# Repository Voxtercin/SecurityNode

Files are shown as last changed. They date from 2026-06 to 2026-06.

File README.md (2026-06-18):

# SecurityNode

SecurityNode is an embedded security system based on an **ESP32-C3** microcontroller and an **ESP32-CAM** vision module. The platform monitors physical access events using external sensors and augments a conventional alarm with event-triggered visual verification.

## Overview

The system is designed around a compact PCB and integrates:

- **ESP32-C3** as the central security controller
- **ESP32-CAM** as an auxiliary vision-processing module
- **Door contact** and **PIR motion sensor** for event detection
- **Alarm LED** and **buzzer** (MOSFET-driven) for local indication
- **USB power input** with **3.3 V regulation**

In the planned operating flow (design-stage; firmware not yet written), when a door-opening or motion event is detected, the ESP32-C3 requests the ESP32-CAM to capture and analyze an image. The vision module is intended to determine whether the person entering has a visible or covered face (e.g., helmet, mask, or balaclava). If a suspicious condition is detected, the ESP32-C3 activates the buzzer and alarm LED.

## Repository Structure

> **Project stage:** this is a **design-stage** project (PCB drawn in Altium but not yet
> fabricated; no firmware written). The documentation and design assets are the current
> deliverable. The code/source directories below — `hardware/altium/`, `firmware/esp32c3/`,
> `firmware/esp32cam/`, `software/host/`, `tests/`, and `tools/` — are currently **skeleton
> placeholders (each holds only a `.gitkeep`)**; the substance lives in `docs/` and `assets/`.

```
SecurityNode/
├── assets/              # PCB renders, schematic blocks, and source PDFs
├── docs/
│   ├── hardware/        # Hardware interface and design documentation
│   ├── firmware/        # Firmware architecture and protocols (proposed design)
│   ├── presentation/    # Final presentation (HTML + PDF)
│   ├── software/        # Host-side tools and utilities (proposed design)
│   ├── system/          # System architecture and requirements
│   └── teacher_notes/   # Presentation guidelines
├── hardware/
│   └── altium/          # Altium Designer project files (skeleton — not yet committed)
├── firmware/
│   ├── esp32c3/         # Main controller firmware (skeleton — not yet written)
│   └── esp32cam/        # Vision module firmware (skeleton — not yet written)
├── software/
│   └── host/            # PC-side configuration and monitoring tools (skeleton)
├── tests/               # Validation procedures and bring-up checklists (skeleton)
└── tools/               # Helper scripts, export helpers, and generators (skeleton)
```

## Modular Architecture

- The ESP32-C3 acts as the **central security controller**, managing sensor inputs and actuators.
- The ESP32-CAM functions as an **auxiliary vision-processing module**.
- The system remains operational as a **basic alarm** even if the vision module is not used.
- Provides an **intelligent upgrade path** for advanced threat detection.

## Academic Context

This project integrates:

- Power regulation
- Digital input conditioning
- Embedded control
- Actuator driving
- Sensor-based event detection
- Computer vision assistance

into a compact PCB-based security platform. It is developed as a **Final Project of Electronic Design**.

## License

This project is licensed under the [MIT License](LICENSE).

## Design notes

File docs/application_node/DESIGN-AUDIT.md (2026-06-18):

# SecurityNode — Design Documentation Audit

> Audit of the SecurityNode docs against the authoritative hardware ground truth
> (schematic netlist `SecurityNode.pdf`, rendered schematic, and Altium LiveBOM
> `SecurityNode.BomDoc`). Design-stage project: PCB drawn in Altium but not built,
> no firmware written. This report separates what is **true** from what is **false**
> so the application note can be fixed against reality.

---

## 1. Verdict & headline

The **high-level architecture is sound and correctly documented** — two MCUs (ESP32-C3 controller + ESP32-CAM vision slave), door/PIR sensing, LED+buzzer alarm, USB power with 3.3 V regulation, and a CAM-absent fallback are all accurate. **The hardware-fact layer is broken**: a single wrong ESP32-C3 pin map and a wrong understanding of two key chips (U4 and U5) were authored speculatively and then propagated into nearly every hardware/firmware doc, the bring-up checklist, the application note, *and* `CLAUDE.md` itself. Firmware written against the current pin tables would not work on the real board, so these are contradictions/fabrications to fix — not acceptable design latitude.

The root causes are few but pervasive: (a) the CAM UART is on the wrong GPIOs, (b) the buzzer is on the wrong GPIO, (c) UART0/programming is mis-described as a "USB-UART through U5" path when the C3 actually uses **native USB**, (d) U5 is called a programming multiplexer when it is an automatic presence-gated isolation switch, (e) U4 is called a whole-board current limiter when it only gates the CAM, and (f) the LDO and a few diode/LED/resistor designators are swapped. Fix those six root facts once and most of the documentation set becomes correct.

---

## 2. Verified correct (keep trusting these)

These claims were checked and **match the schematic/BOM**. They are safe to keep and to build on:

**Concept & system level**
- Two-MCU architecture: **U3 = ESP32-C3-WROOM-02-N4** (controller/master) + **ESP32-CAM** vision module that mounts on header **J3** (UART1 slave). (README, system_overview, firmware_architecture)
- Event flow concept: door/motion → C3 asks CAM to capture+judge face coverage → buzzer+LED if suspicious → degrade to basic alarm if CAM absent/times out. (Correct as a *proposal* — see §5.)
- Power input is **J2 USB Mini-B** (KH-MINI-SMT-5P-Cu), VBUS 5 V, with a 3.3 V regulated rail. (README, system_overview, power_architecture)

**Correct pins (the few that are right)**
- **Door contact = GPIO4** (IO4 / DOOR_GPIO4, from J4). ✔
- **PIR motion = GPIO5** (IO5 / PIR_GPIO5, from J5). ✔
- **Alarm LED = GPIO6** (IO6 / LED_ALERT). ✔ *(pin is right; the LED's designator/resistor are wrong — see §4)*
- Both sensor inputs are inputs; door has real hardware debounce on board. ✔

**Correct parts / topology**
- **Q1 = DN2302S** N-MOSFET, low-side buzzer switch; gate from the buzzer GPIO via **R12 100R**, with **R14 10k** pulldown. ✔ (pin number is wrong, see §3)
- **LS1 = KPEG242-5V** buzzer, on the **5 V rail**, low-side switched by Q1. ✔
- **D5 = XL-2012SURC** red 0805 LED is the actual alarm-LED part. ✔
- **U2 = USBLC6-2P6** ESD array on USB D+/D−; series **R3/R4 22R** to the C3. ✔
- **U4 = TPS2553DBVR** adjustable-ILIM USB power switch (ILIM via R13 21k5); EN via R9 100R. ✔ *(part right; role overstated — see §3)*
- **U1 = AP2112K-3.3** LDO ratings (≤6 V in, 3.3 V/600 mA out, thermal+current limit). ✔ *(ratings right; designator wrong — see §4)*
- **FB1 = HCB1608KF-600T20** ferrite (60 Ω@100 MHz, 2 A, 0603) in the VBUS→5 V path. ✔
- **SW1 = BOOT** (GPIO9, R1 pull-up), **SW2 = EN/reset** (R2 pull-up); manual bootloader = hold SW1, tap SW2. ✔
- The C3↔CAM UART1 link physically runs through **J3** and through **U5**, and both directions pass U5. ✔ (the *pins* and U5's *role description* are wrong elsewhere)
- README contains **no** pin/designator errors (it has no pin numbers) — fully accurate at its level of detail.

---

## 3. Critical errors (must fix) — HIGH severity

These are hardware-fact contradictions or fabrications. Firmware or bring-up done against them will fail. **Recurring** errors are grouped; the same wrong fact appears across many files.

| Location (recurring across docs) | What the docs say | The truth (ground truth) |
|---|---|---|
| **CAM UART1 pins** — mcu_interfaces (GPIO8/9), esp32cam_interface, firmware_architecture, cam_protocol, application_node (A2, pinout, block diag), **CLAUDE.md** | C3↔CAM UART1 is on **GPIO8 / GPIO9** | UART1 is **IO0 = RX (pin18)** and **IO1 = TX (pin17)**, via R20/R21 1k and U5. GPIO8 = STRAP_GPIO8, GPIO9 = BOOT_GPIO9 (SW1 BOOT). Note **IO0=RX, IO1=TX**. |
| **Buzzer pin** — mcu_interfaces, alarm_subsystem, firmware_architecture, application_node (pinout + block diag), **CLAUDE.md** | Buzzer / Q1 gate is on **GPIO7** | Buzzer is **IO10 (BUZZER)** → R12 100R → Q1 gate. **IO7 = CAM_EN** (drives U4 TPS2553 enable via R9), not the buzzer. |
| **Programming / UART0** — mcu_interfaces, firmware_architecture, application_node, **CLAUDE.md** | UART0 debug/programming is **GPIO1/2**, "routed through U5", USB-UART for flashing | UART0 is **RXD=GPIO20 (pin11)** / **TXD=GPIO21 (pin12)**, wired **direct to J1**, **never through U5**. GPIO1=UART1_TX, GPIO2=STRAP_GPIO2. |
| **C3 programmed via "USB-UART bridge"** — mcu_interfaces, firmware_architecture (Arduino step), esp32cam_interface, host_tools, bringup (CP210x), application_node (A6) | C3 is flashed over a USB→UART bridge / CP210x through J2; U5 muxes that UART | **No bridge chip exists.** The C3 is programmed over its **NATIVE USB** (USB-Serial/JTAG): J2 → U2 USBLC6 → R3/R4 22R → IO18(D−)/IO19(D+). PC enumerates the C3's built-in USB CDC, never a CP210x. |
| **BOOT/EN on GPIO0/GPIO3** — mcu_interfaces pinout | GPIO0 = BOOT (SW1); GPIO3 = EN (SW2) | **BOOT is IO9** (BOOT_GPIO9, R1, SW1). **EN is the dedicated EN pin (pin2)**, not a GPIO (ESP_EN, R2, C9, SW2). IO0 = UART1_RX; IO3 = CAM_FAULT. |
| **U4 (TPS2553) role** — system_overview, mcu_interfaces (buzzer "via TPS2553"), power_architecture, alarm_subsystem, application_node, bringup framing | U4 is a whole-board / USB current limiter / "power distribution"; the 5 V rail and buzzer flow through it | U4 is a **dedicated power GATE for the ESP32-CAM only**: IN=5 V rail, OUT=**CAM_5V** (J3 P$9 / J7 pin6). EN via IO7/CAM_EN; ILIM R13 21k5; FAULT→IO3; **R11 100k pulldown holds it OFF by default**. It does **not** feed the 5 V rail, LDO, or buzzer, and does **not** protect the USB host — **F1 PTC fuse** does. |
| **U5 (SN74LVC2G66) role** — system_overview, mcu_interfaces, esp32cam_interface (whole "USB-UART mux" section), host_tools, bringup, application_node | U5 is a USB-to-UART **programming multiplexer** that switches the USB UART between C3 and CAM (CTRL LOW/HIGH, host-selectable) | U5 is a **series isolation/disconnect switch on the C3↔CAM UART1 link only**. Control pins 1C/2C are **hard-tied to CAM_3V3** (the CAM's own 3.3 V output) → **automatic presence-gating**: closes only when a powered CAM is seated, opens when absent. **Not** a USB mux, **not** on UART0/USB, **not** host-controllable. |
| **Omitted PTC fuse F1** — power_architecture power tree | Input chain is TVS → ferrite → USBLC6 (no fuse) | First element after VBUS is **F1 PTC fuse** (Littelfuse 1206L075/16V, 750 mA hold / 1.5 A trip), in series before the D1 clamp and FB1. Whole-board USB over-current = F1, **not** U4. |
| **5 V rail topology** — power_architecture (TPS2553 in series ahead of rail; CAM 5V + buzzer on one node) | TPS2553 feeds the whole 5 V rail and the LDO; CAM 5 V and buzzer share that node | VBUS → F1 → D1+C1 → FB1 → **5 V RAIL**, which feeds **U1 LDO and U4 in parallel** (plus LS1, J5 PIR VCC). **CAM_5V is the gated U4 output (separate node)**; buzzer/PIR are on the ungated 5 V rail. |
| **CAM IO0 driven by C3 GPIO10** — mcu_interfaces (GPIO10=CAM_BOOT), esp32cam_interface | C3 GPIO10 drives CAM IO0 boot strap | **No C3 GPIO drives CAM IO0.** CAM GPIO0 (B_GPIO0_CAM, J3 P$6) is asserted only by the **J6 2-pin jumper** (+ J7 pin4, R17 10k). **IO10 = BUZZER.** |
| **Fabricated aux GPIOs / headers** — mcu_interfaces (GPIO11/12 AUX on J6/J7), sensor_interfaces (J6/J7 expansion, GPIO11/12 spare) | J6/J7 are general-purpose expansion headers exposing spare GPIO11/GPIO12 + 3.3V/5V | **Fabricated.** GPIO11/12 are not broken out (GPIO11 is internal/flash on WROOM). **J6 = 2-pin CAM-GPIO0 download jumper.** **J7 = 6-pin ESP32-CAM programming header** (1=GND, 2=CAM_TXD_RAW, 3=CAM_RXD_RAW, 4=B_GPIO0_CAM, 5=CAM_3V3, 6=CAM_5V). |
| **CAM debug "through the board's USB"** — mcu_interfaces, esp32cam_interface, bringup (USB→CAM switchover) | The CAM is programmed/debugged through the board's USB by switching U5 | The CAM is programmed **out-of-band via J7** with an **external USB-UART adapter** + J6 jumper. No on-board USB path reaches the CAM. |
| **PIR VCC selectable 3.3 V/5 V** — sensor_interfaces | PIR VCC (J5 pin1) can be 3.3 V or 5 V | J5 pin1 (PIR VCC) is **hard-wired to the 5 V rail only**. The board cannot supply 3.3 V to the PIR connector. |
| **J3 pin map** — esp32cam_interface | Generic AI-Thinker order: pin1=3V3, pin3=5V, pin5=TXD, pin6=RXD, pin7=IO0, pins 8-14 = SD/PSRAM GPIOs | Schematic J3: **P$2=CAM_TXD_RAW, P$3=CAM_RXD_RAW, P$6=B_GPIO0_CAM, P$8=CAM_3V3 (CAM's own 3V3, gates U5), P$9=CAM_5V**. SD/PSRAM breakouts are fabricated; CAM_3V3 is **not** fed from the AP2112K. |

**Net pin map to author against (authoritative ESP32-C3 / U3):**

| GPIO | Net / function |
|---|---|
| EN (pin2) | ESP_EN (reset, SW2, R2) |
| IO0 | UART1_RX (CAM link RX, ← R20 1k ← U5) |
| IO1 | UART1_TX (CAM link TX, → R21 1k → U5) |
| IO2 | STRAP_GPIO2 |
| IO3 | CAM_FAULT (← U4 FAULT, R10 10k pull-up) |
| IO4 | DOOR_GPIO4 (door, J4) |
| IO5 | PIR_GPIO5 (PIR, J5) |
| IO6 | LED_ALERT (→ R15 330R → D5) |
| IO7 | CAM_EN (→ R9 100R → U4 EN) |
| IO8 | STRAP_GPIO8 |
| IO9 | BOOT_GPIO9 (BOOT, SW1, R1) |
| IO10 | BUZZER (→ R12 100R → Q1 → LS1) |
| IO18 | USB_D_N (→ R3 22R → U2 → J2) |
| IO19 | USB_D_P (→ R4 22R → U2 → J2) |
| GPIO20 (pin11) | UART0_RX → J1-3 |
| GPIO21 (pin12) | UART0_TX → J1-2 |

---

## 4. Secondary errors — MEDIUM severity

Wrong but lower-blast-radius: mostly designator swaps that mislead bring-up/BOM cross-reference but don't by themselves break firmware logic.

| Location | What the docs say | The truth |
|---|---|---|
| LDO designator — system_overview, esp32cam_interface, power_architecture, bringup, **(appears throughout)** | AP2112K LDO is **U2** | AP2112K-3.3 LDO is **U1**. **U2 = USBLC6** ESD array. (U3=C3, U4=TPS2553, U5=switch.) |
| Alarm LED designator — mcu_interfaces, alarm_subsystem | Alarm LED is **D4**, resistor **R16** | LED is **D5** (XL-2012SURC); series resistor is **R15 330R**. **D4 = BAT54S** PIR clamp; **R16 = 10k** PIR bias. |
| Input TVS designator — power_architecture, bringup | USB input TVS is **D2** | VBUS input TVS (SMF5.0CA) is **D1**. **D2 = PSBD1DF40V1H Schottky 40V 1A** door clamp. |
| J1 pin order — mcu_interfaces | J1: 1=GND, 2=EN, 3=BOOT, 4=RX, 5=TX, 6=GND | J1: 1=GND, **2=UART0_TX (GPIO21), 3=UART0_RX (GPIO20), 4=BOOT_GPIO9, 5=ESP_EN**, 6=GND. |
| Decoupling table — power_architecture | C3=22µF bulk, C4=470nF, specific C5–C16 value map presented as fact | 22µF VBUS bulk is **C1** (not C3; C3 is a 100nF USB-data decoupler); 470nF = C2/C10 (C10=door debounce). The whole designator→value map is inconsistent with the schematic. |
| "5 V unregulated rail" — sensor_interfaces | 5 V pin is an "unregulated rail" | 5 V rail is filtered/protected (F1 PTC + FB1 ferrite + clamps); CAM_5V is additionally **gated/current-limited by U4**. |
| Sensor ESD "not implemented" — sensor_interfaces | No sensor-connector ESD on the PCB | **Partly implemented**: PIR line has **D6** (SMF5.0CA TVS); door has **D2** clamp + RC. |
| GPIO13–21 "unused" — mcu_interfaces | GPIO13–21 free for expansion | GPIO18/19 = native-USB D−/D+; GPIO20/21 = UART0 to J1. In use. |
| Power budget framing — power_architecture, application_node (CAM 200mA@3.3V row) | TPS2553 limit sized as whole-board USB limiter; CAM modeled at 3.3 V 200 mA | U4 gates only the CAM branch (ILIM R13); CAM is fed from **CAM_5V** (gated 5 V), peaks ~500 mA — not 200 mA on 3.3 V. F1 handles whole-board over-current. |
| A4 power rails — application_node | AP2112K 3.3 V rail supplies C3, CAM, sensors, indicators | 3.3 V rail supplies **C3 + U5 only**. CAM runs on **CAM_5V** + its own **CAM_3V3**; PIR + buzzer are on the **5 V rail**. |
| A3 / PIR "3.3 V logic" — application_node | PIR output is a clean 3.3 V logic signal | PIR is **5 V-powered**; signal reaches IO5 through a clamp/divider (R16/R18 100k + BAT54S D4). Qualify accordingly. |
| cam_protocol checksum example — cam_protocol.md line 152 | RESULT example "0xAA 0x02 0x82 0x01 0x80", checksum = 0x80 | `0x02 ^ 0x82 ^ 0x01 = **0x81**`. Frame should be `0xAA 0x02 0x82 0x01 **0x81**`. (Confirmed in file: line 152 prints `= 0x80`.) |

---

## 5. Design proposals (not wrong — but unverifiable, label them "proposed")

These are forward-looking firmware/host/protocol designs. **No firmware or host code exists** (every code dir holds only `.gitkeep`). Nothing in the hardware contradicts them; they are legitimate for a theory-stage note **as long as they are explicitly framed as proposed, not as-built.**

- **CAM UART wire protocol** (cam_protocol.md): frame `0xAA | LENGTH | CMD_ID | PAYLOAD | XOR-checksum`; commands 0x01/0x02/0x03; responses 0x81–0x84; result/status/error code tables; 115200 8N1. Internally consistent **except the one checksum-example arithmetic slip** (§4) and the leftover "let me recalculate" editorial stumble in the CMD_CAPTURE example (~lines 62–82) — clean both up so an implementer doesn't copy a bad literal.
- **FSM**: INIT→ARMED→TRIGGERED→VISION_CHECK→{CLEAR/ALARM}→ARMED, 5 s VISION_CHECK timeout → fallback ALARM, basic-alarm-without-CAM. Consistent across system_overview, firmware_architecture, alarm_subsystem, application_node.
- **Firmware structure / RTOS task layout / build-flash** (PlatformIO primary, ESP-IDF/Arduino alt). Explicitly "Proposed" — fine; only the "USB-UART bridge" wording in the Arduino step is wrong (§3).
- **Host tools** (config util, log viewer, firmware updater, serial monitor, dashboard). Fine — except the two U5 "toggle/select a module" claims, which are hardware-false (§3).
- **Power budget** magnitudes, debounce timings, baud/framing, Wi-Fi/BLE/MQTT/OTA options, vision workflow command names — all acceptable estimates/choices; relabel as proposed and align the CAM rail/load with reality.

---

## 6. Application note (`application_node.tex`) — remediation plan

**Good news first:** the note's **structure is exactly right** for a design deliverable — explicit assumptions table, requirements with traceability matrix, FSM, UART protocol (frame/checksum rule correct), and a theoretical verification plan. The *form* is publishable. The problem is that its **hardware facts were inherited from the wrong source docs** (`mcu_interfaces.md` + the U4/U5 misconceptions), so the technically-checkable content is wrong in the same places as everything else.

**Exact fixes to make in the `.tex`:**

1. **Pinout table (`tab:pinout`, lines ~293–302)** — replace with the authoritative map in §3:
   - BUZZER_DRV: GPIO7 → **GPIO10**.
   - CAM_TX/CAM_RX: GPIO8/GPIO9 → **IO1 (TX) / IO0 (RX)** (and fix the swap: IO0=RX, IO1=TX).
   - USB_TX/USB_RX: GPIO1/GPIO2 "through U5" → **GPIO21/GPIO20, direct to J1, not through U5**.
   - VBUS row: "current-limited by TPS2553" → **"over-current protected by PTC fuse F1; TPS2553 gates CAM_5V only."**
   - Keep DOOR_IN=GPIO4, PIR_IN=GPIO5, ALARM_LED=GPIO6 (correct).
2. **Assumption A2 (line ~158)** — "ESP32-CAM via UART1 (GPIO8/9)" → **"UART1 on IO0=RX / IO1=TX, isolated by U5 (CAM-presence-gated)."** Keep 115200.
3. **Assumption A4 (line ~160) + Power section (lines ~337–339)** — rewrite the rail tree: VBUS→**F1**→D1/C1→**FB1**→5 V rail → (U1 LDO ∥ U4 in parallel). State that the 3.3 V rail feeds **C3 + U5 only**; the CAM is on **CAM_5V (U4-gated)** + its own **CAM_3V3**; PIR + buzzer are on the **5 V rail**. Remove "TPS2553 distributes power [board-wide]."
4. **Assumption A6 (line ~162) + R6** — "USB-UART channel for programming" → **"native USB (USB-Serial/JTAG) on IO18/IO19; separate UART0 debug header J1 on GPIO20/21."** No bridge chip.
5. **U4 / U5 descriptions (power section + PCB checklist line ~396)** — U4 = **CAM-only power gate** (EN via IO7/CAM_EN, ILIM R13 21k5, default-OFF via R11). U5 = **presence-gated series isolation switch on the C3↔CAM UART1 link** (not a programming-path mux). Delete "verify U5 routing for programming-path selection."
6. **Block diagram (`fig:appnode-block`, lines ~258–262)** — buzzer node GPIO7 → **GPIO10**; CAM node GPIO8/9 → **IO0/IO1**; Host node "USB UART0" → **"native USB (IO18/19)"** with UART0/J1 shown as a separate debug header.
7. **Output drive (line ~372)** — "GPIO drives the MOSFET gate directly" → **"via R12 100R series, R14 10k pulldown."**
8. **Power budget (`tab:power`, line ~356)** — move CAM load to **CAM_5V (gated 5 V)** and use the ~500 mA peak the system docs cite, not 200 mA@3.3 V.
9. **Designators** — fix LDO **U1** (not U2), input TVS **D1**, alarm LED **D5**/**R15** anywhere they appear.
10. **Framing** — add an explicit banner: **"Design-stage / not yet fabricated; pin map verified against the schematic netlist."** The note (line ~181) lists `hardware/altium/` as populated source — it currently holds only a `.gitkeep`; relabel artifacts as planned where they don't yet exist.

**Important meta-fix:** `CLAUDE.md` itself encodes the same wrong canonical pin map (GPIO1/2 UART0 "through U5", GPIO7 buzzer, GPIO8/9 CAM UART, U5 "multiplexes the USB UART", TPS2553 as the 5 V switch) and points to `mcu_interfaces.md` as authoritative. **Correct `CLAUDE.md` and `mcu_interfaces.md` first** — they are the upstream that re-seeds every other doc and any future AI edits.

---

## 7. Open questions for the author

1. **Vision approach feasibility (scope this explicitly).** The docs assume the ESP32-CAM can "judge whether a face is covered (mask/helmet/balaclava)" and return a result over UART. If you intend a **pretrained model like YOLO** on the ESP32-CAM, flag the footprint reality: the ESP32 (OV2640 module) is heavily RAM/flash/compute constrained — full YOLO does not fit. Realistic options to evaluate and document as a **decision**: a tiny quantized classifier (e.g. TFLite-Micro / ESP-DL face-or-coverage classifier on small frames), the built-in face-detection primitives, or **offloading inference off-device** (CAM streams a frame; a host/edge does YOLO). The current note treats vision as a black box; pick an approach and write down its memory/latency budget. *(This is the biggest unscoped technical risk in the project.)*

2. **Diode designator split (D1/D3/D6).** BOM has exactly 2× PSBD1DF40V1H (Schottky 40 V 1 A) and 2× SMF5.0CA (TVS 5 V). Only **D2 = Schottky** (schematic prints "40 V 1 A") and **D5 = LED** are certain. The sensible-topology inference is **D1 = VBUS TVS, D3 = 5 V-rail Schottky, D6 = PIR-line TVS**, but per-designator package isn't printed. Confirm from a high-res render or the Altium source before publishing the diode table. **D4 = BAT54S is certain.**

3. **Per-designator R/C → MPN assignment.** The BOM is a value **catalog with no designator column**, so individual R#/C# → exact MPN is inferred from value class + net context. Load-bearing **values** are confirmed (R3/R4=22R, R8/R20/R21=1k, R9/R12=100R, 10k pull-ups, R11/R18/R19=100k, R13=21k5, R15=330R). The exact one-to-one split among same-value parts (e.g. which 100nF is which) is inference — say so, or add a designator column to the BOM.

4. **Sensor conditioning network polarity.** The door (R7 10k / R8 1k / C10 470nF / D2) and PIR (R16/R18 100k, C13/C17, D4, D6) networks' exact pull-up-vs-divider roles and active polarity are inferred from net topology, not annotated. Confirm active-low vs active-high before writing the ISR logic. (The GPIO↔net assignment IO4=door, IO5=PIR is certain.)

5. **BOM hygiene cleanup** (catalogued separately): the SMF5.0CA TVS is mislabeled "TVS 12V" (it's 5 V); the 100nF cap description says "0201" but the footprint is 0603; F1 has a stray "YTL " prefix on the MPN; J2 lists manufacturer EDAC but the MPN is Kinghelm; several parts use non-standard `MF=`/`MP=` keys or corrupted `… Pad Number` keys that drop out of standard exports; the YAGEO 100k links to the wrong (84.5 Ω) datasheet. Worth a pass before any real fabrication/quote.

6. **Connector MPNs.** Only J2 (Mini-USB) and J3 (ESP32-CAM) are catalogued. J1/J4/J5/J6/J7 pin counts/roles are read from schematic symbols, not a catalogued part — assign real connector parts before fabrication.

---

*Audit basis: schematic netlist (authoritative on disagreement), rendered schematic, and Altium LiveBOM. Where three independent passes disagreed, the netlist won.*

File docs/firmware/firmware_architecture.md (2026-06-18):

# Firmware Architecture — SecurityNode

> **Status: PROPOSED / design-stage.** No firmware exists yet (the code directories
> currently hold only `.gitkeep`). Everything in this document — the FSM, the RTOS
> task layout, the proposed `src/` file structure, and the build/flash instructions —
> is a planned design, not as-built. Pin references have been corrected against the
> authoritative schematic netlist (see `docs/application_node/DESIGN-AUDIT.md`).

## Overview

The SecurityNode firmware runs on the **ESP32-C3-WROOM-02-N4** and is responsible for:

1. Sensor input monitoring (door contact, PIR)
2. Alarm output control (buzzer, LED)
3. Communication with the ESP32-CAM vision module
4. System state management and decision logic
5. UART0 debug/console interface (programming itself is over native USB — see *Build and Flash*)

## Main Firmware Loop

```
[Setup]
    |
    +-- Initialize GPIOs
    +-- Initialize UARTs (UART0 debug/console + UART1 CAM link)
    +-- Initialize Wi-Fi (optional, for remote monitoring)
    +-- Set initial state: ARMED
    |
    v
[Main Loop]
    |
    +-- Read sensor inputs (IO4 door, IO5 PIR)
    +-- Evaluate state machine
    +-- Handle UART1 commands from CAM
    +-- Handle UART0 / USB-CDC commands (debug / config)
    +-- Update alarm outputs
    +-- Sleep / yield to RTOS
    |
    v
[Repeat]
```

## State Machine (Proposed)

> Proposed FSM — no firmware implements this yet.

The core of the firmware is a finite-state machine (FSM) that governs system behavior:

```
                    +-----------+
                    |   INIT    |
                    +-----+-----+
                          |
                          v
                    +-----------+
        +---------->|   ARMED   |<----------+
        |           +----+------+           |
        |                |                  |
        |    [No trigger]|   [Sensor event]  |
        |                |                  |
        |                v                  |
        |           +-----------+           |
        |           | TRIGGERED |           |
        |           +----+------+           |
        |                |                  |
        |                v                  |
        |           +-----------+           |
        |           |  VISION   |           |
        |           |  CHECK    |           |
        |           +----+------+           |
        |                |                  |
        |   +------------+------------+      |
        |   |                         |      |
        |   v                         v      |
        | +-----------+           +-----------+ |
        | |  CLEAR    |           |  ALARM    | |
        | |  (safe)   |           |  (active) | |
        | +----+------+           +----+------+ |
        |      |                         |      |
        |      |   [Disarm / timeout]    |      |
        |      |                         |      |
        +------+-------------------------+------+
```

### State Descriptions

| State | Description | Entry Actions | Exit Actions |
|---|---|---|---|
| **INIT** | System startup, self-test | Initialize hardware, test LED/buzzer, check CAM presence | Transition to ARMED |
| **ARMED** | Normal monitoring mode | LED slow blink (1Hz), buzzer OFF, sensors active | — |
| **TRIGGERED** | Sensor event detected | LED fast blink (4Hz), send CMD_CAPTURE to CAM | — |
| **VISION_CHECK** | Waiting for CAM analysis | Maintain fast blink, start 5s timeout timer | — |
| **CLEAR** | CAM reports visible face | Log event, return to ARMED | — |
| **ALARM** | CAM reports suspicious or timeout | LED solid ON, buzzer ON, log event | Wait for disarm or timeout |

## Sensor Input Handling

### Interrupt-Driven vs. Polling

Two approaches are supported:

**Interrupt-Driven (Recommended)**
- Configure IO4 (door, J4) and IO5 (PIR, J5) with `GPIO_INTR_POSEDGE` or `GPIO_INTR_NEGEDGE`.
- ISR sets a flag; main loop processes the flag to avoid long ISRs.
- Low power: ESP32-C3 can enter light sleep and wake on GPIO interrupt.

**Polling**
- Read GPIO states every 50–100ms in the main loop.
- Simpler but higher power consumption and slightly slower response.

### Debounce

- Software timer: ignore state changes within 50ms of the first transition.
- Prevents false triggers from mechanical switch bounce (door contact) or PIR module instability.

> Note: the door has on-board RC hardware debounce, and the PIR is powered from the
> **5V rail** (not 3.3V) with its output conditioned by a clamp/divider network before
> reaching IO5. The active polarity (active-high vs active-low) of both inputs is
> inferred from the conditioning network topology and is **to be confirmed** against the
> schematic before the ISR edge/level logic is finalized.

## UART Communication

### UART0 Debug Header (direct to J1)

| Parameter | Value |
|---|---|
| Port | UART0 (RX = GPIO20 / pin11, TX = GPIO21 / pin12) |
| Routing | Wired **direct to header J1**, NOT through U5 |
| Baud Rate | 115200 |
| Purpose | Debug logs, console, configuration commands; alternate flash header |

> Note: this is a plain UART0 debug/console header. It is **not** the primary
> programming path — the C3 is flashed over its native USB (see *Build and Flash*).

### ESP32-CAM Link UART

| Parameter | Value |
|---|---|
| Port | UART1 (RX = **IO0** / pin18 ← R20 1k ← U5, TX = **IO1** / pin17 → R21 1k → U5) |
| Baud Rate | 115200 |
| Purpose | Capture commands, result codes, status messages |

> Note the direction: **IO0 = UART1_RX, IO1 = UART1_TX**. The link passes through
> **U5 (SN74LVC2G66)**, a CAM-presence-gated series isolation switch whose control pins
> are hard-tied to the CAM's own 3.3V (`CAM_3V3`). U5 auto-connects the link only when a
> powered CAM is seated and auto-disconnects when the CAM is absent/off — firmware does
> **not** control U5, and it is **not** a programming multiplexer.

### UART Command Protocol

See `docs/firmware/cam_protocol.md` for detailed message format.

## Alarm Output Control

### LED (IO6 → R15 330R → D5)

```cpp
// Example (Arduino-style pseudocode)
digitalWrite(ALARM_LED_PIN, HIGH);   // Alarm ON
digitalWrite(ALARM_LED_PIN, LOW);    // Alarm OFF

// Blink pattern
void blinkLED(int freqHz, int durationMs) {
    int periodMs = 1000 / freqHz;
    int cycles = durationMs / periodMs;
    for (int i = 0; i < cycles; i++) {
        digitalWrite(ALARM_LED_PIN, HIGH);
        delay(periodMs / 2);
        digitalWrite(ALARM_LED_PIN, LOW);
        delay(periodMs / 2);
    }
}
```

### Buzzer (IO10 → R12 100R → Q1 DN2302S → LS1)

```cpp
digitalWrite(BUZZER_PIN, HIGH);   // Buzzer ON
digitalWrite(BUZZER_PIN, LOW);    // Buzzer OFF

// Pulsed tone
void pulseBuzzer(int onMs, int offMs, int cycles) {
    for (int i = 0; i < cycles; i++) {
        digitalWrite(BUZZER_PIN, HIGH);
        delay(onMs);
        digitalWrite(BUZZER_PIN, LOW);
        delay(offMs);
    }
}
```

## ESP32-CAM Power Gate Control (IO7 / IO3)

The ESP32-CAM's 5V supply (`CAM_5V`) is gated by **U4 (TPS2553)**, not powered
continuously. The C3 controls and monitors this gate:

| Signal | Pin | Direction | Role |
|---|-----|---|---|
| CAM_EN | **IO7** (→ R9 100R → U4 EN) | Output | Drive HIGH to enable the CAM 5V gate; held OFF by default at boot (R11 100k pulldown on U4 EN) |
| CAM_FAULT | **IO3** (← U4 FAULT, R10 10k pull-up) | Input | Active-low fault flag from U4 (over-current / thermal); read to detect CAM power faults |

> Proposed sequencing: the gate is off at reset, so firmware should drive IO7 HIGH to
> power the CAM before attempting any UART1 capture, allow the CAM to boot, then watch
> IO3 for a fault. The U5 isolation switch will only connect the UART1 link once the
> powered CAM asserts its own `CAM_3V3`, so a brief settle delay after enabling the gate
> is expected. (Behavior is proposed; no firmware implements it yet.)

## Wi-Fi and Networking (Optional)

The ESP32-C3 includes Wi-Fi and Bluetooth LE. Potential features:

- **Remote monitoring**: Publish sensor events and alarm status to MQTT broker.
- **OTA updates**: Firmware updates over Wi-Fi.
- **Mobile app**: Simple web server or BLE interface for arming/disarming.
- **Cloud logging**: Send images or event logs to a remote server.

> Note: Wi-Fi operation increases power consumption. Consider deep-sleep strategies if battery operation is desired.

## File Structure (Proposed)

```
firmware/esp32c3/
├── src/
│   ├── main.cpp              # Entry point, setup(), loop()
│   ├── state_machine.cpp     # FSM implementation
│   ├── state_machine.h
│   ├── sensors.cpp           # Door contact, PIR input handling
│   ├── sensors.h
│   ├── alarm.cpp             # Buzzer and LED control
│   ├── alarm.h
│   ├── cam_uart.cpp          # ESP32-CAM communication
│   ├── cam_uart.h
│   ├── debug_uart.cpp        # UART0 debug / CLI (native-USB CDC + J1 header)
│   ├── debug_uart.h
│   └── config.h              # Pin definitions, timeouts, constants
├── lib/                      # External libraries (if any)
├── platformio.ini            # PlatformIO configuration (if used)
└── README.md                 # Build and flash instructions
```

## Build and Flash (Proposed)

> Proposed toolchain/workflow — no firmware project exists yet (the `firmware/esp32c3/`
> tree holds only a `.gitkeep`). The directory layout above and the commands below are
> the planned setup.
>
> **Programming path:** the ESP32-C3 is flashed over its **native USB
> (USB-Serial/JTAG)** — J2 Mini-USB → U2 USBLC6 ESD → R3/R4 22R → IO18 (D−) / IO19 (D+).
> There is **no USB-UART bridge chip (no CP210x/CH340)** on this board; the host
> enumerates the C3's built-in USB CDC/JTAG device directly. To force the bootloader
> manually, hold SW1 (BOOT, IO9) and tap SW2 (EN/reset). Header J1 is an **alternate**
> UART0 flash/debug path (GPIO20/21) if you prefer wiring an external adapter.

### Using PlatformIO (Recommended)

```bash
cd firmware/esp32c3
platformio run --target upload   # uploads over the native USB serial/JTAG port
```

### Using Arduino IDE

1. Install ESP32 board support (ESP32-C3 variant).
2. Select board: "ESP32C3 Dev Module".
3. Select the serial port that enumerates when J2 is plugged in — this is the C3's
   **native USB (USB-Serial/JTAG)** device, not a USB-UART bridge port.
4. Upload sketch (hold SW1 + tap SW2 first if the board does not auto-enter the
   bootloader).

### Using ESP-IDF

```bash
cd firmware/esp32c3
idf.py set-target esp32c3
idf.py build
idf.py flash
```

## Design Notes (Proposed)

> Proposed implementation guidance and RTOS task layout — design-stage, not yet built.

- Keep ISRs short: set flags and defer processing to the main loop or a FreeRTOS task.
- Use a ring buffer for UART1 receive to handle asynchronous CAM responses.
- Implement a watchdog timer (ESP32-C3 has a hardware TWDT) to recover from firmware hangs.
- **Proposed FreeRTOS task layout:** separate tasks for sensor polling (IO4/IO5),
  UART1 CAM-link handling (IO0/IO1), alarm output control (IO6 LED, IO10 buzzer), and
  CAM power-gate supervision (IO7 enable / IO3 fault). This is a proposed decomposition
  to improve responsiveness; the exact task count and priorities are to be decided when
  firmware is written.
- Store configuration (Wi-Fi credentials, sensitivity thresholds) in NVS (Non-Volatile Storage) to persist across reboots.

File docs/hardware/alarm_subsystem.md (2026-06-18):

# Alarm Subsystem — SecurityNode

## Overview

The alarm subsystem provides local visual and audible indication when the SecurityNode detects a suspicious event. It consists of:

1. **Alarm LED** (D5) — Red 0805 SMD LED
2. **Buzzer** (LS1) — KPEG242-5V electromagnetic buzzer

Both indicators are controlled by the ESP32-C3 (U3) through dedicated GPIO pins.

## Alarm LED (D5)

### Circuit

```
ESP32-C3 GPIO6 ──[R15: 330Ω]──|>|── GND
                              D5
                              (RED LED)
```

### Parameters

| Parameter | Value |
|---|---|
| LED | XINGLIGHT XL-2012SURC (RED, 0805 package) |
| Forward voltage (Vf) | ~2.0V |
| Forward current (If) | ~4mA (typical) |
| Current-limiting resistor (R15) | 330Ω |
| Current calculation | (3.3V – 2.0V) / 330Ω ≈ 3.9mA |

### Behavior

- GPIO6 **HIGH** → LED ON (alarm active / triggered).
- GPIO6 **LOW** → LED OFF (idle / standby).
- The LED can be blinked in firmware to indicate different states (e.g., slow blink = armed, fast blink = alarm active). *(Proposed firmware behavior.)*

## Buzzer (LS1)

### Circuit

```
5V Rail ──[+] LS1 [-]── Q1 Drain
                         |
                         Q1 Source ── GND
                         |
                     Q1 Gate ──[R12: 100Ω]── ESP32-C3 GPIO10
                                  |
                                  [R14: 10kΩ]── GND (pulldown)
```

### Components

| Component | Part Number | Function |
|---|---|---|
| Buzzer | KPEG242-5V | Electromagnetic buzzer, 5V rated (on the 5V rail) |
| MOSFET | DN2302S (Q1) | N-channel MOSFET, 20V / 3.2A, SOT-23, low-side switch |
| Gate resistor | R12 (100Ω) | Limits inrush current to gate, reduces ringing |
| Gate pulldown | R14 (10kΩ) | Ensures MOSFET is OFF during ESP32-C3 boot / GPIO floating |

### Parameters

| Parameter | Value |
|---|---|
| Gate threshold voltage (Vgs(th)) | ~1.0–1.5V (logic-level compatible) |
| Rds(on) at Vgs=3.3V | Low enough for buzzer current (< 100mA) |
| Buzzer current | ~30–100mA depending on type and sound level |
| Gate pulldown resistor (R14) | 10kΩ–100kΩ typical |

### Behavior

- GPIO10 **HIGH** (3.3V) → Q1 turns ON → buzzer sounds.
- GPIO10 **LOW** (0V) → Q1 turns OFF → buzzer silent.
- The buzzer can be pulsed in firmware to generate different tones or patterns (e.g., continuous = intrusion, intermittent = warning). *(Proposed firmware behavior.)*

### MOSFET Selection Rationale

The **DN2302S** was chosen because:

- **Low Vgs(th)** — Fully enhanced at 3.3V gate drive from ESP32-C3.
- **Low Rds(on)** — Minimizes voltage drop and heat dissipation at buzzer current levels.
- **Small package** — SOT-23 fits compact PCB layout.
- **Adequate current rating** — 3.2A continuous is well above the ~100mA buzzer requirement, providing margin.

## Alarm Activation Logic (Proposed)

> **Design-stage:** the state machine below is a *proposed* firmware design. No firmware
> is committed yet, so the logic, timeouts, and patterns are planned, not as-built.

The firmware is intended to control the alarm outputs based on the following state machine:

```
[ARMED / IDLE]
    |
    +-- Sensor Triggered (door / PIR)
    |       |
    |       v
    |   [VISION CHECK]
    |       |
    |       +-- ESP32-CAM reports "suspicious" (covered face)
    |       |       |
    |       |       v
    |       |   [ALARM ON]
    |       |       |
    |       |       +-- Buzzer ON (continuous or pulsed)
    |       |       +-- LED ON (continuous or fast blink)
    |       |       |
    |       |       +-- Timeout / User Disarm
    |       |               |
    |       |               v
    |       |           [ALARM OFF]
    |       |               |
    |       |               v
    |       |           [Return to ARMED]
    |       |
    |       +-- ESP32-CAM reports "clear" (visible face)
    |       |       |
    |       |       v
    |       |   [LOG EVENT]
    |       |       |
    |       |       v
    |       |   [Return to ARMED]
    |       |
    |       +-- ESP32-CAM timeout / not connected
    |               |
    |               v
    |           [Fallback: ALARM ON]
    |               |
    |               v
    |           [Return to ARMED]
    |
    +-- No trigger
            |
            v
        [Remain in ARMED]
```

## Alarm Patterns (Suggested Firmware Implementation)

| State | LED Pattern | Buzzer Pattern |
|---|---|---|
| Armed / Idle | Slow blink (1Hz) | Off |
| Sensor Triggered | Fast blink (4Hz) | Off |
| Vision Analysis | Fast blink (4Hz) | Off |
| Alarm Active | Solid ON | Continuous tone |
| Disarmed / Safe | Solid OFF | Off |
| Error / CAM disconnected | Double blink | Single chirp every 10s |

## Safety and Reliability

- The gate pulldown resistor (R14, 10kΩ) ensures the buzzer cannot accidentally activate during ESP32-C3 boot when GPIOs are in high-impedance state.
- The current-limiting resistor (R15, 330Ω) protects the LED from overcurrent if the GPIO drive strength is higher than expected.
- Whole-board USB over-current protection is provided by the **F1 PTC resettable fuse** (Littelfuse 1206L075, 750mA hold / 1.5A trip) in series on the VBUS input — *not* by U4. The buzzer and LED draw from the protected 5V rail downstream of F1, so a buzzer or 5V-load short is cleared by F1. (U4/TPS2553 is a dedicated power gate for the ESP32-CAM only; it does not feed the buzzer or the 5V rail.)
- If the buzzer is too loud for the intended environment, consider PWM drive at lower duty cycle or a series resistor.

## Design Notes

- The buzzer is low-side switched on the 5V rail directly, not the 3.3V LDO, to avoid overloading the AP2112K regulator (U1).
- Verify buzzer polarity if using a polarized electromagnetic type; reverse connection will not damage the device but may reduce sound output.
- The KPEG242-5V part in the BOM appears to be an electromagnetic buzzer; confirm the exact pinout and sound level before finalizing the firmware alarm patterns.

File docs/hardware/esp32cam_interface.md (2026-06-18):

# ESP32-CAM Interface — SecurityNode

## Overview

The **ESP32-CAM** module is connected to the SecurityNode main board via a dedicated header (J3). It serves as the auxiliary vision-processing module, capturing images and performing face-coverage analysis upon request from the ESP32-C3 controller.

> **Stage:** SecurityNode is a **design-stage / not-yet-fabricated** project. The hardware facts below (J3 pinout, power gating, U4/U5 roles, programming path) are verified against the schematic netlist (`assets/SecurityNode.pdf`). The UART message flow and vision workflow are a **proposed firmware design** — no firmware exists yet — and are labeled as such.

## Physical Connection — J3 Header

The ESP32-CAM module (commonly the AI-Thinker variant with OV2640 camera) mounts onto the board through header J3. Only the nets actually used by SecurityNode are broken out: power, ground, the UART1 link, and the CAM boot strap. The SD-card / PSRAM GPIO breakouts are *not* routed on this board.

### Pinout (J3 — from the schematic netlist)

| J3 Pin | Net | Function | Connected To |
|---|-----|---|---|
| P$2 | CAM_TXD_RAW | CAM UART TX (CAM U0TXD/GPIO1 → C3) | ESP32-C3 **IO0 (UART1_RX)**, via U5 + R20 1k |
| P$3 | CAM_RXD_RAW | CAM UART RX (CAM U0RXD/GPIO3 ← C3) | ESP32-C3 **IO1 (UART1_TX)**, via U5 + R21 1k |
| P$6 | B_GPIO0_CAM | CAM boot / GPIO0 strap | J6 2-pin boot jumper / J7 pin4 (not driven by the C3) |
| P$8 | CAM_3V3 | CAM 3.3V (the CAM module's own regulator output) | Local to CAM; also the **U5 control input** (presence gate) |
| P$9 | CAM_5V | Gated 5V supply to the CAM | **U4 (TPS2553) output** (U4 IN = 5V rail) |

> GND pins are present on the connector and tie to the global ground plane.

> **Note:** CAM_3V3 is the ESP32-CAM module's *own* internal regulator output, not the main-board AP2112K (U1) 3.3V rail. The C3↔CAM UART nets pass through the U5 isolation switch (see below). Cross-reference any change against `assets/SecurityNode.pdf` (schematic = ground truth).

## Power Supply

The ESP32-CAM is supplied **only with gated 5V** from the main board (`CAM_5V`). Its 3.3V logic/sensor supply (`CAM_3V3`) is generated by the ESP32-CAM module's **own on-board regulator** — the main-board AP2112K (U1) does *not* feed the CAM:

| Rail | Source | Purpose |
|---|---|---|
| CAM_5V | **TPS2553 (U4)** gated output (U4 IN = 5V rail) | Sole power input to the ESP32-CAM module (its internal 5V→3.3V regulator and RF) |
| CAM_3V3 | **ESP32-CAM module's own internal regulator** | I/O logic, camera sensor digital supply; also drives the U5 presence-gate control (P$8) |

### Power Considerations

- The ESP32-CAM can draw up to **500mA peak** during Wi-Fi transmission + camera operation.
- The 5V to the CAM is **gated and current-limited by U4 (TPS2553)**: enabled by the C3 via IO7/CAM_EN (→ R9 100R → U4 EN), current limit set by R13 (21k5), with FAULT reported back to the C3 on IO3/CAM_FAULT. U4 is held **OFF by default** during C3 boot by R11 (100k pulldown). Ensure the R13 current-limit threshold is above the CAM's peak draw.
- The main-board AP2112K (U1) 3.3V rail powers **only the C3 (U3) and U5** — it is not loaded by the CAM, so CAM current does not affect the 3.3V budget.
- Place decoupling capacitors close to J3 for the CAM_5V input; the CAM_3V3 decoupling lives on the CAM module itself.

## UART Communication

A dedicated UART channel connects the ESP32-C3 and the ESP32-CAM over **UART1**. It is independent of the C3's own programming/console path (the C3 is flashed over native USB on IO18/IO19, with UART0 on GPIO20/21 broken out to the J1 debug header). The CAM link physically passes through the U5 isolation switch (see below); it does **not** share any wire with the USB or UART0 path.

| Parameter | Value |
|---|---|
| UART Port | ESP32-C3 UART1 — **IO0 = RX, IO1 = TX** (via U5 + R20/R21 1k) |
| Baud Rate | 115200 (default) |
| Data Bits | 8 |
| Parity | None |
| Stop Bits | 1 |
| Flow Control | None |

> **Direction note:** On the C3, **IO0 is the RX** (receives the CAM's TX, CAM_TXD_RAW) and **IO1 is the TX** (drives the CAM's RX, CAM_RXD_RAW). GPIO8 and GPIO9 are *not* on this link — they are STRAP_GPIO8 and the BOOT button (SW1) respectively.

### Message Flow *(proposed firmware design — not yet implemented)*

```
ESP32-C3                      ESP32-CAM
   |                               |
   |--- CMD_CAPTURE --------------->|
   |                               |
   |<-- ACK_CAPTURE ---------------|
   |                               |
   |                               | [Capture image]
   |                               | [Run face analysis]
   |                               |
   |<-- RESULT (CLEAR/SUSPICIOUS) --|
   |                               |
```

Detailed command structure is documented in `docs/firmware/cam_protocol.md`.

## Boot and Programming

The ESP32-CAM is **not** programmed through the SecurityNode board's USB connector. There is no on-board USB path to the CAM, and U5 is **not** a programming multiplexer (see the U5 section below). The CAM is flashed out-of-band:

### Programming via J7 + External USB-UART Adapter

- Header **J7** (6-pin) breaks out the CAM's raw programming nets: `[1=GND, 2=CAM_TXD_RAW, 3=CAM_RXD_RAW, 4=B_GPIO0_CAM, 5=CAM_3V3, 6=CAM_5V]`.
- Connect an **external USB-to-UART adapter** (e.g. an FTDI/CP210x dongle) to J7: adapter RX ↔ CAM_TXD_RAW, adapter TX ↔ CAM_RXD_RAW, common GND.
- The CAM's GPIO0 boot strap (`B_GPIO0_CAM`) is asserted by the **J6 2-pin jumper** (also exposed on J7 pin4 + R17 10k) — *not* by any ESP32-C3 GPIO.

### Entering ESP32-CAM Bootloader Mode

1. Connect the external USB-UART adapter to J7 (TXD/RXD/GND).
2. Hold CAM GPIO0 LOW by fitting the **J6 boot jumper** (B_GPIO0_CAM).
3. Power-cycle / reset the ESP32-CAM.
4. The ESP32-CAM enters UART download mode; flash with `esptool`/IDE.
5. Remove the J6 jumper and reset for normal (run) operation.

> The ESP32-C3 *could* in firmware act as an application-level UART relay over the UART1 link for remote/in-field updates, but that is a proposed/design-stage feature and is not a hardware programming path — the as-built flashing method is J7 + external adapter.

## Analog Switch — SN74LVC2G66DCTR (U5)

### Function

U5 is a 2-channel **analog switch used as an automatic, CAM-presence-gated series isolation switch** on the C3↔CAM **UART1** link. Each of the two channels sits in series with one UART line (CAM_TXD/RXD_RAW ↔ the C3-side _ISO nets), connecting the C3 to the CAM only when a powered CAM module is seated.

It is **not** a USB-to-UART programming multiplexer, it is **not** host- or GPIO-selectable, and it does **not** touch the USB or UART0 path.

| U5 control (1C / 2C) tied to | UART1 link state | Condition |
|---|---|---|
| CAM_3V3 present (≈ HIGH) | **Connected** | A powered ESP32-CAM is seated (its own 3.3V is up) |
| CAM_3V3 absent (≈ LOW) | **Isolated** | CAM not installed or unpowered |

### Control Logic

- U5's control pins (1C / 2C) are **hard-tied to CAM_3V3** — the ESP32-CAM module's own 3.3V regulator output (J3 P$8). There is no microcontroller or jumper control of U5.
- This makes the UART link **auto-connect** when a powered CAM is present and **auto-disconnect** when the CAM is absent or off, isolating the C3's UART1 pins from a floating/dead connector.
- The switch has low on-state resistance (~few Ω), so it does not meaningfully degrade the signal at 115200 baud.

## Vision Processing Workflow *(proposed firmware design — not yet implemented)*

1. **Trigger**: Door open or PIR motion event detected by ESP32-C3.
2. **Command**: ESP32-C3 sends `CMD_CAPTURE` to ESP32-CAM via UART.
3. **Capture**: ESP32-CAM captures a frame from the OV2640 camera.
4. **Analysis**: ESP32-CAM runs face detection / coverage algorithm (e.g., Haar cascade, lightweight CNN, or simple skin-tone analysis).
5. **Result**: ESP32-CAM returns one of:
   - `RESULT_CLEAR` — face is visible, no threat detected.
   - `RESULT_SUSPICIOUS` — face is covered (mask, helmet, balaclava), threat detected.
   - `RESULT_ERROR` — capture or analysis failed.
6. **Action**: ESP32-C3 evaluates result and activates alarm if necessary.

## Module Isolation

The modular architecture allows the system to operate without the ESP32-CAM:

| Scenario | ESP32-CAM | ESP32-C3 Behavior |
|---|---|---|
| CAM connected and responsive | Active | Full vision-assisted alarm mode |
| CAM connected but not responding | Unresponsive | Timeout after 5s → fallback to basic alarm |
| CAM not installed | Absent | Basic alarm mode (sensor → immediate alarm) |

## Design Notes

- The ESP32-CAM AI-Thinker module includes an on-board PCB antenna; ensure no copper pours or traces block the antenna area on the main PCB.
- The camera ribbon cable (OV2640) connects to the ESP32-CAM module, not the main board. Ensure adequate clearance for the camera module.
- Keep the UART1 traces between the ESP32-C3, U5, and J3 short and matched in length to minimize skew.
- The ESP32-CAM supplies its own 3.3V (CAM_3V3) from its on-board regulator; the main-board AP2112K (U1) 3.3V rail is not loaded by the CAM, so no extra 3.3V regulator is needed for the CAM module.
- The AI-Thinker ESP32-CAM does not have an on-board USB-to-UART bridge; therefore external programming is required, done via header **J7** with an external USB-UART (FTDI/CP210x) adapter plus the J6 boot jumper. U5 is an automatic UART isolation switch and is **not** a programming path.

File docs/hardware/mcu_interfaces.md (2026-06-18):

# MCU Interfaces — SecurityNode

## Main Controller: ESP32-C3-WROOM-02-N4 (U3)

The ESP32-C3-WROOM-02-N4 is the central security controller. It manages sensor inputs, alarm outputs, and communicates with the ESP32-CAM vision module.

> **Design stage:** this is a not-yet-fabricated board. The hardware pin map and topology below are verified against the schematic netlist; any firmware/protocol behavior referenced is **proposed** design, not as-built.

## Pinout Mapping

> Note: This table is the authoritative ESP32-C3 (U3) pin map, taken from the schematic netlist (`assets/SecurityNode.pdf`) and the Altium BOM. It supersedes earlier speculative tables. Note the UART1 direction: **IO0 = RX, IO1 = TX**.

| ESP32-C3 Pin | Function | Connected To | Description |
|---|---|---|---|
| EN (dedicated pin 2) | ESP_EN | SW2 + R2 (and Header J1) | Chip enable / reset — dedicated EN pin, not a GPIO |
| IO0 | UART1_RX | ← R20 (1k) ← U5 ← J3 (CAM TXD) | CAM-link UART RX (from ESP32-CAM) |
| IO1 | UART1_TX | → R21 (1k) → U5 → J3 (CAM RXD) | CAM-link UART TX (to ESP32-CAM) |
| IO2 | STRAP_GPIO2 | — | Boot strap pin |
| IO3 | CAM_FAULT | U4 (TPS2553) FAULT, R10 10k pull-up | Input: CAM power-gate fault flag (active-low) |
| IO4 | DOOR_GPIO4 | J4 (Door Contact) | Digital input: door open/close |
| IO5 | PIR_GPIO5 | J5 (PIR Motion, PIR powered from 5V) | Digital input: motion detected |
| IO6 | LED_ALERT | → R15 (330Ω) → D5 (LED) | Drives alarm status LED |
| IO7 | CAM_EN | → R9 (100Ω) → U4 (TPS2553) EN | Output: enables the ESP32-CAM power gate |
| IO8 | STRAP_GPIO8 | — | Boot strap pin |
| IO9 | BOOT_GPIO9 | SW1 + R1 (and Header J1) | BOOT button / boot mode strap |
| IO10 | BUZZER | → R12 (100Ω) → Q1 gate (DN2302S) → LS1 | N-MOSFET gate drive for buzzer |
| IO18 | USB_D_N | → R3 (22Ω) → U2 (USBLC6) → J2 | Native USB D− (USB-Serial/JTAG) |
| IO19 | USB_D_P | → R4 (22Ω) → U2 (USBLC6) → J2 | Native USB D+ (USB-Serial/JTAG) |
| GPIO20 (pin 11) | UART0_RX | Header J1 (pin 3), direct | Debug/console UART RX — not through U5 |
| GPIO21 (pin 12) | UART0_TX | Header J1 (pin 2), direct | Debug/console UART TX — not through U5 |
| 3.3V | Power | U1 (AP2112K-3.3) output | Logic rail supply (C3 + U5 only) |
| GND | Ground | Global ground | Common return |

## Programming Interface

The ESP32-C3 is programmed over its **native USB** (the built-in USB-Serial/JTAG peripheral) through the Mini USB connector (J2). There is **no USB-UART bridge chip** on the board (no CP210x / no FTDI): J2 connects through U2 (USBLC6 ESD protection) and R3/R4 (22Ω series) to IO18 (D−) / IO19 (D+). The PC enumerates the C3's built-in USB CDC device directly.

- **Native USB (primary)**: J2 → U2 → IO18/IO19. Used for flashing, debug output, and logs.
- **UART0 debug/flash header (J1, alternate)**: GPIO20 (RX) / GPIO21 (TX) are wired **direct to J1**, not through U5. This header, together with the BOOT/EN buttons, is an alternate path for `esptool.py` flashing or serial console.

> The SN74LVC2G66DCTR (U5) does **not** participate in programming. It only isolates the C3↔CAM UART1 link (see "UART Protocol to ESP32-CAM" below). The ESP32-CAM is programmed out-of-band via J7 with an external USB-UART adapter — no on-board USB path reaches the CAM.

### Entering Bootloader Mode

1. Hold **SW1 (BOOT, IO9)** pressed.
2. Press and release **SW2 (EN, dedicated EN pin)**.
3. Release **SW1**.
4. ESP32-C3 enters download mode, ready for `esptool.py` or Arduino IDE upload over native USB (or via the J1 UART0 header).

## Sensor Input Conditioning

Door contact (IO4) and PIR motion (IO5) sensors are connected through connector headers J4 and J5. The PIR is **powered from the 5V rail** (J5 VCC is hard-wired to 5V; the board cannot supply 3.3V to that connector), and its output reaches IO5 through an on-board conditioning network. The inputs are characterized as follows:

- **Pull-up / bias**: external resistors are present on the conditioning networks (10kΩ–100kΩ class); internal pull-ups can also be enabled in firmware.
- **Active polarity**: to be confirmed against the schematic — the exact pull-up-vs-divider role and active-low/active-high polarity of the door (R7/R8/C10/D2) and PIR (R16/R18/BAT54S D4) networks are inferred from net topology, not annotated. Confirm before writing ISR logic.
- **Debounce**: the door line has real hardware debounce on board (RC filter); additional debounce can be implemented in firmware (software timer).

## Alarm Output Control

### Buzzer (LS1) — Q1 (DN2302S) N-MOSFET Driver

| Parameter | Value |
|---|---|
| MOSFET | DN2302S (20V, 3.2A, SOT-23) |
| Gate drive | ESP32-C3 IO10 (BUZZER) via series resistor R12 (100Ω) |
| Gate pulldown | R14 (10k, to ensure OFF state at boot) |
| Source | GND |
| Drain | Buzzer negative terminal |
| Buzzer positive | 5V rail (ungated — not via U4/TPS2553) |

When IO10 is HIGH, the MOSFET turns on, sinking current through the buzzer. The buzzer is a **KPEG242-5V** electromagnetic type (LS1), rated for 5V operation, and sits on the ungated 5V rail (U4/TPS2553 gates the CAM branch only, not the buzzer).

### Alarm LED (D5)

- Designator: **D5** (XL-2012SURC), red 0805 SMD LED (~2V forward voltage)
- Current-limiting resistor: **R15** (330Ω)
- Driven directly by ESP32-C3 IO6 (LED_ALERT, 3.3V logic)
- LED current: ~(3.3V – 2.0V) / 330Ω ≈ 4mA

## UART Protocol to ESP32-CAM

The ESP32-C3 communicates with the ESP32-CAM via a dedicated UART1 port on **IO0 (RX)** and **IO1 (TX)** (each via a 1kΩ series resistor, R20/R21), separate from the native-USB programming path. This link runs through header J3 and through the U5 isolation switch.

**U5 (SN74LVC2G66DCTR) — automatic CAM-presence-gated UART isolation:** U5 is a 2-channel analog switch wired as a **series isolation/disconnect switch on the C3↔CAM UART1 link only** (CAM_TXD/RXD_RAW ↔ the _ISO nets). Its control pins (1C/2C) are **hard-tied to CAM_3V3** — the ESP32-CAM module's own internal 3.3V regulator output. As a result the UART link **auto-connects only when a powered CAM is seated** in J3 and **auto-disconnects when the CAM is absent or off**. It is **not** a USB-to-UART programming multiplexer, is **not** host- or GPIO-selectable, and does not touch UART0/USB.

| Parameter | Value |
|---|---|
| Baud Rate | 115200 (default) |
| Data Bits | 8 |
| Parity | None |
| Stop Bits | 1 |
| Flow Control | None |

> The CAM UART command structure and response codes are a **proposed (design-stage)** protocol documented in `docs/firmware/cam_protocol.md` — no firmware is implemented yet.

## Headers

### J1 — Alternate UART0 Debug / Flash Header

| Pin | Signal | Description |
|-----|---|---|
| 1 | GND | Ground |
| 2 | UART0_TX (GPIO21) | UART0 TX, direct from C3 (not through U5) |
| 3 | UART0_RX (GPIO20) | UART0 RX, direct to C3 (not through U5) |
| 4 | BOOT_GPIO9 | Boot mode strap (SW1 / IO9) |
| 5 | ESP_EN | Chip enable / reset (SW2 / dedicated EN pin) |
| 6 | GND | Ground |

### J6 — ESP32-CAM Boot Jumper

A **2-pin jumper** that asserts the ESP32-CAM's GPIO0 (B_GPIO0_CAM) for download mode. No C3 GPIO drives this strap — it is a manual jumper (with J7 pin 4 and R17 10k). It is **not** an auxiliary GPIO expansion header.

### J7 — ESP32-CAM Programming Header

A **6-pin** out-of-band programming header for the ESP32-CAM, used with an **external USB-UART adapter** (plus the J6 boot jumper). No on-board USB path reaches the CAM through this header.

| Pin | Signal | Description |
|-----|---|---|
| 1 | GND | Ground |
| 2 | CAM_TXD_RAW | ESP32-CAM U0TXD |
| 3 | CAM_RXD_RAW | ESP32-CAM U0RXD |
| 4 | B_GPIO0_CAM | ESP32-CAM GPIO0 boot strap |
| 5 | CAM_3V3 | ESP32-CAM 3.3V (module's own regulator output) |
| 6 | CAM_5V | ESP32-CAM gated 5V (U4 output) |

> The ESP32-C3 does **not** break out general-purpose aux GPIOs (e.g. GPIO11–17 are not available on the WROOM-02 module). There are no auxiliary expansion headers exposing spare C3 GPIOs.

## Design Notes

- All GPIOs operate at 3.3V logic levels. Do not connect 5V logic directly to ESP32-C3 pins. (The PIR runs on 5V; its output is conditioned on board before reaching IO5.)
- The ESP32-C3 has internal pull-up/pull-down resistors that can be enabled in firmware, reducing the need for external resistors on digital inputs.
- The alarm LED is driven directly by IO6 (via R15); the buzzer is driven through Q1 (DN2302S) from IO10 (via R12) — both are low-current loads.
- The U5 analog switch needs **no firmware management**: it is presence-gated by CAM_3V3 in hardware, so the C3↔CAM UART1 link connects/disconnects automatically with CAM presence and cannot create host-side bus contention.
- The 3.3V rail (U1 / AP2112K-3.3) supplies the C3 and U5 only; the buzzer and PIR are on the 5V rail; the CAM runs on the U4-gated CAM_5V plus its own CAM_3V3.

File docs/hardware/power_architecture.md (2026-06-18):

# Power Architecture — SecurityNode

> **Design-stage / not-yet-fabricated.** Power topology below is verified against the
> schematic netlist (`assets/SecurityNode.pdf`) and Altium BOM (`assets/SecurityNode.BomDoc`).

## Power Tree

```
USB 5V Input — VBUS (J2)
    |
    v
F1 -- PTC resettable fuse (Littelfuse 1206L075, 750mA hold / 1.5A trip)
    |     <-- whole-board USB over-current protection lives HERE
    v
D1 (SMF5.0CA TVS) -- input transient clamp   +   C1 22uF -- bulk hold-up
    |
    v
FB1 -- Ferrite Bead (60Ω@100MHz) -- EMI filtering
    |
    v
5V RAIL  (filtered + protected; ungated)
    |
    +---> U1 (AP2112K-3.3) LDO  ----> 3.3V RAIL
    |                                   |
    |                                   +---> ESP32-C3-WROOM-02-N4 (U3)
    |                                   +---> SN74LVC2G66DCTR (U5)
    |                                   +---> logic pull-ups
    |
    +---> U4 (TPS2553DBVR) CAM power GATE ----> CAM_5V  (gated node)
    |        EN <- IO7/CAM_EN (via R9 100R)        |
    |        ILIM set by R13 21k5                   +---> ESP32-CAM 5V (J3 P$9 / J7 pin6)
    |        FAULT -> IO3/CAM_FAULT                 |
    |        default OFF (R11 100k pulldown)        (CAM also runs its own CAM_3V3,
    |                                                the CAM module's internal regulator)
    +---> LS1 KPEG242-5V buzzer (low-side switched by Q1)
    |
    +---> J5 PIR VCC (PIR is powered from 5V only)

USB data lines (D+/D-) are separately ESD-protected by U2 (USBLC6-2P6)
on the J2 → R3/R4 22R → IO18/IO19 native-USB path (not in the power rail above).
```

## Key Components

### Whole-Board Over-Current — F1 (Littelfuse 1206L075 PTC fuse)

- Resettable PTC fuse, **first element after VBUS** (1206 package)
- 750 mA hold / 1.5 A trip; protects the USB host and the whole board from over-current
- This — not U4 — is the board's over-current limiter on the USB input

### Input Protection — D1 (SMF5.0CA)

- Bidirectional TVS diode clamping VBUS transients (designator is **D1**, not D2; D2 is the door-line Schottky)
- 5V working voltage, clamps USB plug-in spikes / ESD on the 5V input
- Paired with C1 22µF bulk capacitor for input hold-up and decoupling

### EMI Filter — FB1 (TAI-TECH HCB1608KF-600T20)

- 60Ω @ 100MHz, 2A ferrite bead in 0603 package
- Sits between the input clamp and the 5V rail; isolates board switching/digital noise from the USB host

### ESD Protection — U2 (USBLC6-2P6)

- SOT-666-6 ESD diode array
- Protects USB D+ and D- data lines (IO19/IO18 native USB) from static discharge
- On the USB **data** path only (J2 → R3/R4 22R → U2 → IO18/IO19); not in the power rail

### ESP32-CAM Power Gate — U4 (TPS2553DBVR)

- **Dedicated power gate for the ESP32-CAM branch only** — IN = 5V rail, OUT = CAM_5V (J3 P$9 / J7 pin6)
- Enabled by the C3 via **IO7/CAM_EN** (through R9 100R); held **OFF by default** by R11 100k pulldown during C3 boot
- Adjustable current limit set by **R13 (21k5)**; on-resistance ~85mΩ; soft-start; reverse blocking
- FAULT output fed back to the C3 on **IO3/CAM_FAULT** (R10 10k pull-up)
- Does **not** feed the 5V rail, the LDO, or the buzzer, and does **not** protect the USB host (F1 does)

### 3.3V LDO — U1 (AP2112K-3.3TRG1)

- Designator is **U1** (not U2 — U2 is the USBLC6 ESD array)
- Input: up to 6V (here ~5V directly from the ungated 5V rail)
- Output: fixed 3.3V ± 2%
- Maximum output current: 600mA
- Low dropout, low quiescent current — suitable for battery-friendly designs
- Thermal shutdown and current limit protection built-in
- Feeds the **3.3V rail, which powers only U3 (the C3), U5, and logic pull-ups**

## Decoupling Strategy

The schematic uses a conventional bulk + local-decoupling scheme; exact per-designator
capacitor assignments are **to be confirmed against the Altium source** (the BOM is a value
catalog without a designator column, so individual C# → value/MPN is inferred from net context).
Qualitatively:

- **C1 = 22µF** bulk hold-up on the **VBUS input** (this is the input bulk cap — *not* C3; C3 is a
  100nF decoupler on the USB data domain).
- **470nF** decoupling appears on the analog/sensor and rail nodes (e.g. C2; C10 is the door-line
  debounce cap, not a power decoupler).
- The **3.3V rail** carries bulk decoupling (µF-class) plus local 100nF caps at each IC power pin
  (U3, U5).
- Each IC supply pin (U1 in/out, U4 in/out, U3, U5) has a local 100nF (and where appropriate a
  µF-class) decoupling capacitor near its power pin.

> The previously published per-designator value table (C3=22µF, C4=470nF, C5–C16 = fixed map)
> did not match the schematic and has been removed; treat the above as the design intent until the
> Altium designator map is confirmed.

## Power Budget (Estimated — proposed/design-stage figures)

> Magnitudes below are design-stage estimates, not measured. Note the **rail each load sits on**:
> the CAM is fed from the **gated CAM_5V** node (via U4), the buzzer and PIR from the **ungated 5V
> rail**, and only the C3 / U5 / logic from the **3.3V rail**.

| Load | Rail | Current (typ) | Current (max) |
|---|---|---|---|
| ESP32-C3-WROOM-02-N4 (U3) | 3.3V | 80mA | 300mA (Wi-Fi TX peak) |
| ESP32-CAM | CAM_5V (gated by U4) + own CAM_3V3 | 180mA | ~500mA (Wi-Fi + camera peak) |
| Buzzer (LS1) | 5V | 30mA | 100mA |
| Alarm LED (D5) | 3.3V (via IO6 → R15 330R) | 5mA | 20mA |
| PIR sensor (J5) | 5V | 1mA | 10mA |
| Door contact (J4) | 3.3V logic | <1mA | <1mA |
| SN74LVC2G66 (U5) | 3.3V | 1uA | 10uA |
| Other logic / pull-ups | 3.3V | 5mA | 15mA |
| **Total Estimated** | — | **~300mA** | **~950mA** |

> Notes:
> - **Whole-board USB over-current is bounded by F1** (PTC, 750 mA hold / 1.5 A trip), not by U4.
> - **U4's adjustable current limit (R13 = 21k5) bounds only the CAM_5V branch** — it must be set
>   above the CAM's ~500 mA peak yet within what the upstream 5V rail / USB host can deliver.
> - The CAM is on the **gated 5V** node (CAM_5V), not on the 3.3V rail — earlier "200 mA @ 3.3V"
>   figures for the CAM were incorrect.
> - If total board load approaches USB-host capability (typically 500 mA for standard USB 2.0), a
>   higher-current source or external 5V supply may be required.

## Design Notes

- The ferrite bead (FB1) + input bulk capacitor (C1) form a filter that reduces conducted EMI from the switching/digital loads back to the USB host.
- The AP2112K (U1, 600mA) only has to supply the **C3, U5, and logic pull-ups** on the 3.3V rail — the ESP32-CAM does **not** draw from this rail, so the LDO is comfortably sized.
- The ESP32-CAM receives **CAM_5V** (gated by U4, J3 P$9) for its internal regulator, and supplies its **own** CAM_3V3 (the CAM module's internal regulator output, J3 P$8) — the board's AP2112K does **not** feed the CAM's 3.3V.
- The CAM branch is **off by default** at power-up (R11 100k holds U4 disabled) and is enabled by the C3 asserting IO7/CAM_EN, giving the controller explicit power control and over-current sensing (FAULT → IO3) of the camera.
- Reverse-voltage protection: the TPS2553 (U4) provides reverse blocking on the gated CAM branch. A 40V/1A Schottky (PSBD1DF40V1H) is present on the board's diode complement; the exact designator on the 5V path (vs. the door clamp D2) is **to be confirmed against the Altium source** — only D2 = Schottky and D5 = LED are certain from the current data.

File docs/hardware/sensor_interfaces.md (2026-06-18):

# Sensor Interfaces — SecurityNode

## Supported Sensors

The SecurityNode board provides dedicated connectors for two primary sensor types:

1. **Door Contact Switch** — Magnetic or mechanical reed switch
2. **PIR Motion Sensor** — Passive infrared motion detector

> Note: J6 and J7 are **not** general-purpose sensor-expansion headers. J6 is the 2-pin ESP32-CAM GPIO0 boot/download jumper and J7 is the 6-pin ESP32-CAM programming header (see `esp32cam_interface.md`). The board exposes no spare digital-sensor expansion connectors.

## Door Contact (J4)

### Electrical Interface

| Parameter | Specification |
|---|---|
| Connector | 2-pin header (J4) |
| Switch type | Normally-closed (NC) or normally-open (NO) reed/magnetic contact |
| Logic level | 3.3V (ESP32-C3 GPIO4) |
| Input conditioning | On-board RC debounce network (around R7 10kΩ / R8 1kΩ / C10 470nF) plus a Schottky clamp (D2, PSBD1DF40V1H) on the door line — hardware debounce is present on the PCB, not firmware-only. Exact pull-up-vs-divider polarity is inferred from the net layout and to be confirmed against the Altium source. |
| Trigger condition | Contact open (HIGH → LOW transition, or LOW → HIGH depending on wiring) |

### Typical Wiring

```
ESP32-C3 GPIO4 ──[10kΩ pull-up]── 3.3V
                 |
                 +── J4 Pin 1 (Switch terminal A)
                 |
J4 Pin 2 (Switch terminal B) ── GND
```

When the door is **closed**, the switch is closed and GPIO4 reads LOW (pulled to GND).
When the door is **open**, the switch opens and GPIO4 reads HIGH (pulled up to 3.3V).

> Note: The active logic can be inverted in firmware if a normally-open switch is used instead.

### Firmware Handling (proposed)

> Design-stage guidance; no firmware exists yet.

- Configure GPIO4 as a digital input (internal pull-up may be redundant given the on-board RC network — confirm against the schematic before relying on it).
- Use **interrupt-on-change** or **polling** to detect state transitions.
- On-board hardware debounce (C10 RC network) already filters most contact bounce; an optional software debounce (e.g., 50ms timer) can add margin.

## PIR Motion Sensor (J5)

### Electrical Interface

| Parameter | Specification |
|---|---|
| Connector | 3-pin header (J5): VCC, OUT, GND |
| Supply voltage | **5V only** — J5 pin 1 (VCC) is hard-wired to the 5V rail. The board cannot supply 3.3V to this connector. |
| Output type | Digital TTL/CMOS logic (5V-referenced at the module) |
| On-board conditioning | PIR output reaches GPIO5 through a clamp/divider network (R16/R18 100kΩ + BAT54S dual Schottky D4) — the GPIO does **not** see a raw clean 3.3V logic level; the network clamps/limits the 5V-referenced output before the C3 pin. |
| Trigger condition | Motion detected → output HIGH (or LOW, depending on module) |

### Typical Wiring

```
J5 Pin 1 (VCC) ── 5V rail (hard-wired; not selectable)
J5 Pin 2 (OUT) ── [on-board clamp/divider: R16/R18 100k + BAT54S D4] ── ESP32-C3 GPIO5
J5 Pin 3 (GND) ── GND
```

> The on-board conditioning network (R16/R18 100kΩ + BAT54S dual Schottky D4) clamps and limits the 5V-referenced PIR output so it is safe to present to the 3.3V GPIO5 input. The exact pull-up-vs-divider topology and active polarity are inferred from the schematic net layout and should be confirmed against the Altium source before finalizing firmware ISR logic.

Most common HC-SR501 or similar PIR modules:
- Output goes **HIGH** for a configurable duration (typically 2–200 seconds) when motion is detected.
- Output is **LOW** when no motion is present.
- Some modules have a retriggerable mode (continuous HIGH while motion persists) and a single-shot mode.

### Firmware Handling (proposed)

> Design-stage guidance; no firmware exists yet.

- Configure GPIO5 as a digital input. The on-board R16/R18 + BAT54S D4 network conditions the line; select internal pull/no-pull to match the network's resting state once the conditioning polarity is confirmed against the schematic.
- Use **interrupt-on-rising-edge** to wake the system or trigger event processing.
- Respect the PIR module's minimum trigger interval to avoid false re-triggers.

## Sensor Event Logic

> **Proposed / design-stage:** the event-priority table and alarm sequence below describe planned firmware behavior. No firmware exists yet, so treat this as the intended design rather than as-built logic.

The firmware evaluates sensor inputs with the following priority:

| Priority | Event | Action |
|---|---|---|
| 1 | Door open detected | Trigger alarm sequence |
| 2 | PIR motion detected | Trigger alarm sequence |
| 3 | Both simultaneously | Trigger alarm sequence (same path) |

The alarm sequence is:

1. Log timestamp and sensor type.
2. Request image capture from ESP32-CAM.
3. Wait for vision analysis result (timeout: e.g., 5 seconds).
4. If result = **suspicious / covered face** → activate buzzer + LED.
5. If result = **visible face** or **timeout** → log event, return to idle.

## Input Protection

- All sensor connectors are routed to ESP32-C3 GPIOs which tolerate 0–3.3V.
- No high-voltage or analog interfaces are present on the sensor headers.
- On-board clamping/ESD is **partly implemented** on both sensor lines:
  - **Door (J4):** Schottky clamp **D2** (PSBD1DF40V1H, 40V/1A) plus an RC conditioning/debounce network.
  - **PIR (J5):** TVS clamp (SMF5.0CA, the diode in the PIR-line position — designator to be confirmed against the Altium source) plus the R16/R18 100kΩ + BAT54S D4 clamp/divider.
- For sensors mounted remotely on long cables, additional external protection may still be worth considering for production, but the board is **not** unprotected at the connectors.

## J6 / J7 — Not Sensor Connectors

J6 and J7 are **not** auxiliary sensor-expansion headers and do **not** break out spare GPIOs. GPIO11–GPIO17 are not available on the ESP32-C3-WROOM-02 module (GPIO11 and adjacent pins are used internally for flash), so no such expansion exists. For completeness:

| Header | Role |
|---|---|
| **J6** | 2-pin ESP32-CAM GPIO0 boot/download jumper |
| **J7** | 6-pin ESP32-CAM programming header (GND, CAM_TXD_RAW, CAM_RXD_RAW, B_GPIO0_CAM, CAM_3V3, CAM_5V) |

Both relate to programming the ESP32-CAM out-of-band with an external USB-UART adapter; see `esp32cam_interface.md`.

## Design Notes

- J5 supplies the PIR with **5V** (hard-wired), which suits common 5V PIR modules (e.g. HC-SR501). There is no 3.3V option on this connector, so use a PIR module that runs on 5V.
- The PIR output does not reach GPIO5 directly: the on-board R16/R18 100kΩ + BAT54S D4 network clamps/limits the 5V-referenced output before the 3.3V GPIO. No external level-shifter is required for this board.
- Door contact switches are passive and polarity-agnostic; however, consistent wiring (common to GND, signal to GPIO) simplifies firmware logic.
- Series-R / small-C EMI conditioning is already present on the door line (RC network around D2) and a clamp/divider on the PIR line; for unusually long remote cable runs, additional external filtering can still be considered.

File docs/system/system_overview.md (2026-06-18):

# System Overview — SecurityNode

## Project Description

SecurityNode is an embedded security system based on an **ESP32-C3-WROOM-02-N4** microcontroller and an **ESP32-CAM** vision module. The platform monitors physical access events using external sensors and augments a conventional alarm with event-triggered visual verification.

## Functional Requirements

1. **Sensor Monitoring**: Continuously monitor door contact and PIR motion sensor inputs.
2. **Event Detection**: Trigger an alarm sequence when a door-opening or motion event is detected.
3. **Visual Verification**: Request the ESP32-CAM module to capture and analyze an image of the detected event.
4. **Threat Assessment**: Determine if the detected person has a visible or covered face (e.g., helmet, mask, or balaclava).
5. **Alarm Activation**: Activate local alarm indicators (buzzer and LED) if a suspicious condition is detected.
6. **Modular Operation**: Remain operational as a basic alarm even if the vision module is not connected or active.

## Use Cases

> **Design-stage note:** The behavior below describes the *proposed* firmware/FSM. This is a design-stage, not-yet-fabricated project — no firmware exists yet. The flow is the intended design, not as-built behavior.

### Primary Use Case: Intrusion Detection with Visual Verification

```
[Idle State]
    |
    v
[Door Open / Motion Detected]
    |
    v
[Trigger ESP32-CAM Capture]
    |
    v
[Analyze Image — Face Visible?]
    |-- NO / Covered --> [Activate Buzzer + LED]
    |
    |-- YES / Clear ----> [Log Event, Return to Idle]
    |
    v
[Return to Idle]
```

### Fallback Use Case: Basic Alarm Mode

If the ESP32-CAM module is not available or vision analysis fails, the ESP32-C3 acts as a standalone alarm controller, activating outputs on any sensor event.

## System Block Diagram

```
+------------------+   UART1 (IO0=RX/IO1=TX)    +------------------+
|                  |<------------------------->|                  |
|   ESP32-C3       |  via U5 isolation -> J3    |   ESP32-CAM      |
|   (Controller)   |                            |   (Vision)       |
|                  |                            |                  |
+--------+---------+                            +--------+---------+
         |                                               |
         | GPIO                                          | Camera
         |                                               | Sensor
    +----+----+                                    +-----+-----+
    |         |                                    |           |
+---v---+ +---v----+                          +----v----+ +----v----+
| Buzzer| | Alarm  |                          |  Lens   | |  Wi-Fi  |
| (LS1) | | LED    |                          +---------+ | Antenna |
+-------+ +--------+                                      +---------+
         |
         | GPIO
    +----+----+
    |         |
+---v---+ +---v----+
| Door  | |  PIR   |
|Contact| |Motion  |
+-------+ +--------+
         |
         | Native USB (IO18/IO19) + 5V power in
    +----v----+
    | Mini USB|
    |   (J2)  |
    +---------+
```

## Key Components Summary

| Module | Component | Role |
|---|---|---|
| Main Controller | ESP32-C3-WROOM-02-N4 | Security logic, sensor polling, alarm control, UART master |
| Vision Module | ESP32-CAM (via J3) | Image capture, face coverage analysis, UART slave |
| Power Input | Mini USB B (J2) | 5V DC supply |
| 3.3V Regulator | AP2112K-3.3TRG1 (U1) | LDO supplying the 3.3V rail (ESP32-C3 + U5 + logic pull-ups) |
| ESP32-CAM Power Gate | TPS2553DBVR (U4) | Current-limited power switch that gates the CAM 5V branch (CAM_5V) only; enabled by CAM_EN, OFF by default |
| CAM-UART Isolation Switch | SN74LVC2G66DCTR (U5) | Analog switch on the C3↔CAM UART1 link; auto-connects/isolates based on CAM presence (control tied to CAM_3V3) |
| Buzzer Driver | DN2302S (Q1) | N-channel MOSFET for buzzer activation |
| Alarm LED | LED_0805_RED | Visual alarm indicator |
| ESD Protection | USBLC6-2P6, SMF5.0CA | Transient voltage suppression on USB and power lines |

## Academic Context

This project integrates:

- Power regulation and distribution
- Digital input conditioning
- Embedded control and state machines
- Actuator driving (MOSFET)
- Sensor-based event detection
- Computer vision assistance
- Inter-module communication protocols

into a compact, modular PCB-based security platform.

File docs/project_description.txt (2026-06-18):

**Project Description — SecurityNode**

SecurityNode is an embedded security system based on an ESP32-C3 microcontroller and an ESP32-CAM vision module. The system is designed to monitor physical access events using external sensors such as a door contact, PIR motion sensor, the ESP32-C3 supervises the sensor inputs and controls the local alarm indicators with an alarm LED, and a buzzer driven through a MOSFET stage. The current schematic includes the main USB power input, 3.3 V regulation, ESP32-C3 control unit, sensor interfaces, visual indicators, buzzer output, and an ESP32-CAM daughter-board connector. 

The main purpose of the project is to improve a conventional alarm system by adding event-triggered visual verification. When a door-opening or motion event is detected, the ESP32-C3 can request the ESP32-CAM module to capture and analyze an image. The vision module may then determine whether the person entering has a visible or covered face, for example due to a helmet, mask, or balaclava. If a suspicious condition is detected, the ESP32-C3 activates the buzzer and alarm LED.

In academic terms, the project integrates power regulation, digital input conditioning, embedded control, actuator driving, sensor-based event detection, and computer vision assistance into a compact PCB-based security platform. The ESP32-C3 acts as the central security controller, while the ESP32-CAM functions as an auxiliary vision-processing module. This modular architecture allows the system to remain operational as a basic alarm even if the vision module is not used, while still providing an intelligent upgrade path for advanced threat detection.
The ESP32-C3 used is a ESP32-C3-WROOM-02-N4

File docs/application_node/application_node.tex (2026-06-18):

\documentclass[11pt,a4paper]{article}

% -----------------------------------------------------------------------------
% Packages
% -----------------------------------------------------------------------------
\usepackage[margin=2.5cm]{geometry}
\usepackage[utf8]{inputenc}
\usepackage[T1]{fontenc}
\usepackage{lmodern}   % scalable Type-1 fonts; required so microtype font-expansion works on a fresh MiKTeX
\usepackage{microtype}
\usepackage{amsmath}
\usepackage{booktabs}
\usepackage{longtable}
\usepackage{array}
\usepackage{float}
\usepackage{graphicx}
\graphicspath{{../presentation/images/schematic_blocks/}{../presentation/images/}}
\usepackage{xcolor}
\usepackage{listings}
\usepackage{hyperref}
\usepackage{enumitem}
\usepackage{tikz}
\usetikzlibrary{arrows.meta, positioning, shapes, fit, calc, automata}

% Allow slightly looser line breaking to avoid overfull boxes in tables/lists.
\emergencystretch=1em

% -----------------------------------------------------------------------------
% Colors and styles
% -----------------------------------------------------------------------------
\definecolor{nodeblue}{RGB}{63, 114, 175}
\definecolor{nodegreen}{RGB}{46, 139, 87}
\definecolor{nodered}{RGB}{192, 57, 43}
\definecolor{nodegray}{RGB}{120, 120, 120}
\definecolor{backgray}{RGB}{245, 245, 245}

\tikzset{
    appnode/.style={
        rectangle,
        rounded corners=4pt,
        draw=nodeblue,
        fill=nodeblue!10,
        line width=1.2pt,
        minimum width=4.2cm,
        minimum height=2.2cm,
        align=center,
        font=\sffamily\small
    },
    io/.style={
        rectangle,
        rounded corners=3pt,
        draw=#1,
        fill=#1!8,
        line width=1pt,
        minimum width=2.8cm,
        minimum height=1cm,
        align=center,
        font=\sffamily\small
    },
    bus/.style={
        ->,
        >=Stealth,
        line width=1pt
    },
    databus/.style={
        <->,
        >=Stealth,
        line width=1pt,
        dashed
    }
}

\lstset{
    basicstyle=\ttfamily\small,
    backgroundcolor=\color{backgray},
    frame=single,
    framerule=0pt,
    breaklines=true,
    columns=flexible,
    keepspaces=true
}

% -----------------------------------------------------------------------------
% Metadata
% -----------------------------------------------------------------------------
\title{
    \textbf{SecurityNode}\\[0.4em]
    \Large Application Note\\
    Controller / Application Node Design
}
\author{Final Project of Electronic Design}
\date{Version~1.1 (schematic-verified) --- \today}

\begin{document}

\maketitle

\begin{abstract}
This application note documents the \textbf{design} of the SecurityNode
controller/application node.  The node is implemented on the
ESP32-C3-WROOM-02-N4 and is responsible for sensor monitoring, alarm control,
vision-module coordination, and host communication.  Because the project is
still at the design stage and no assembled hardware is available, this note
focuses on architectural choices, electrical interfaces, requirements and
traceability, a formal state machine, the UART protocol, and a theoretical
verification plan.  Measured bench data such as oscilloscope waveforms, thermal
tests, and power-consumption plots are intentionally excluded.

\medskip
\noindent\textbf{Status and verification note:} This is a design-stage,
not-yet-fabricated project: no hardware has been built and no firmware has been
written.  The \emph{pin map and electrical facts} in this note (pinout, power
tree, U4/U5 roles, designators) are \textbf{verified against the schematic
netlist}.  All \emph{firmware, communication-protocol, finite-state-machine,
and host-tool content is a PROPOSED design}, not as-built, and is labelled as
such throughout.
\end{abstract}

\begin{center}\small
\begin{tabular}{@{}clp{8.4cm}@{}}
\toprule
\textbf{Rev.} & \textbf{Date} & \textbf{Change} \\
\midrule
1.0 & --- & Initial design-stage application note. \\
1.1 & \today & Pinout, power tree, and U4/U5 roles corrected and verified against the schematic netlist; schematic/PCB figures, component-value rationale, key-components table, and references added. \\
\bottomrule
\end{tabular}
\end{center}

\tableofcontents
\newpage

% -----------------------------------------------------------------------------
\section{Purpose and scope}
% -----------------------------------------------------------------------------

This application note has three objectives:

\begin{enumerate}
    \item Capture the design intent of the SecurityNode application/controller node.
    \item Provide enough detail for a peer review of the firmware architecture,
        electrical interfaces, and communication protocol before hardware is built.
    \item Define the verification activities that can be performed analytically
        or by inspection, given that no physical prototype exists yet.
\end{enumerate}

The note covers:

\begin{itemize}
    \item Design assumptions and constraints.
    \item Design artifacts produced by the project.
    \item Functional requirements and a traceability matrix.
    \item External interfaces and a formal pinout.
    \item Electrical design summary and review notes.
    \item Finite-state machine with a camera-availability flag.
    \item UART protocol interface between the ESP32-C3 and the ESP32-CAM.
    \item Firmware design sketch.
    \item Theoretical verification plan.
\end{itemize}

The following topics are \textbf{out of scope} until hardware is fabricated:
measured waveforms, oscilloscope captures, thermal performance, real power
consumption, and PCB bring-up results.

% -----------------------------------------------------------------------------
\section{Design assumptions}
% -----------------------------------------------------------------------------

The design described in this note relies on the assumptions listed in
Table~\ref{tab:assumptions}.

\begin{table}[H]
    \centering
    \caption{Design assumptions.}
    \label{tab:assumptions}
    \begin{tabular}{@{}clp{8cm}@{}}
        \toprule
        \textbf{ID} & \textbf{Area} & \textbf{Assumption} \\
        \midrule
        A1 & Controller & The application node runs on an ESP32-C3-WROOM-02-N4. \\
        A2 & Vision & The ESP32-CAM is connected through UART1 on IO0=RX / IO1=TX (auto-isolated by U5, a CAM-presence-gated series switch) at 115200~baud. \\
        A3 & Sensors & The door contact and PIR (the PIR is 5~V-powered, its signal reaching the C3 through a clamp/divider network) reach the C3 as logic-level signals; polarity is configurable in firmware. \\
        A4 & Power & The board is powered from a 5~V USB source through a PTC fuse (F1); a 5~V rail then feeds, in parallel, the 3.3~V LDO (U1) for the C3+U5 logic and the CAM power gate (U4). \\
        A5 & Outputs & The buzzer is driven by a low-side N-channel MOSFET (Q1, DN2302S); the alarm LED (D5) has a series current-limiting resistor (R15, 330~$\Omega$). \\
        A6 & Host & The C3 is programmed and debugged over its \textbf{native USB} (USB-Serial/JTAG, IO18/IO19); a separate UART0 debug header (J1, GPIO20/21) is also provided. No USB-UART bridge chip is present. \\
        A7 & Algorithm & The ESP32-CAM returns one of the result codes defined in the CAM protocol; the C3 does not run vision inference. The on-device vision approach is a \emph{deliberately open design decision} (see \S\ref{sec:vision}). \\
        A8 & Backup & No battery backup is provided; the system operates from USB power only. \\
        \bottomrule
    \end{tabular}
\end{table}

% -----------------------------------------------------------------------------
\section{Design artifacts}
% -----------------------------------------------------------------------------

The following artifacts are part of the SecurityNode design baseline and are
referenced throughout this note:

\begin{itemize}
    \item \texttt{docs/system/system\_overview.md} --- System description and block diagram.
    \item \texttt{docs/firmware/firmware\_architecture.md} --- Firmware structure and build options.
    \item \texttt{docs/firmware/cam\_protocol.md} --- Binary UART protocol specification.
    \item \texttt{docs/hardware/} --- Hardware interface notes and design rationale.
    \item \texttt{hardware/altium/} --- \emph{Planned} Altium schematic and PCB source files (directory is currently a placeholder; the schematic netlist and BOM are the present source of truth).
    \item \texttt{firmware/}, \texttt{software/host/} --- \emph{Planned} firmware and host-tool source (directories are currently placeholders; no code written yet).
    \item \texttt{assets/Schematic Blocks/} --- Schematic-block previews.
    \item \texttt{assets/pcb.pdf} --- PCB fabrication preview.
    \item This document --- Application Note for the controller node.
\end{itemize}

% -----------------------------------------------------------------------------
\section{Requirements}
% -----------------------------------------------------------------------------

\begin{table}[H]
    \centering
    \caption{Controller/Application Node functional requirements.}
    \label{tab:requirements}
    \begin{tabular}{>{\raggedright\arraybackslash}p{0.7cm} >{\raggedright\arraybackslash}p{3.6cm} >{\raggedright\arraybackslash}p{4.5cm} c >{\raggedright\arraybackslash}p{2.6cm}}
        \toprule
        \textbf{ID} & \textbf{Requirement} & \textbf{Rationale} & \textbf{Priority} & \textbf{Verification} \\
        \midrule
        R1 & Monitor door contact continuously. & Detect unauthorized entry. & High & Inspection / Analysis \\
        R2 & Monitor PIR motion continuously. & Detect movement inside the protected area. & High & Inspection / Analysis \\
        R3 & Request visual verification from the ESP32-CAM on a sensor event. & Gate the alarm on visual evidence: catch masked / covered-face intruders while suppressing benign triggers. & High & Protocol review \\
        R4 & Activate the local alarm when a suspicious condition is detected. & Deter intruders and alert occupants. & High & State-machine review \\
        R5 & Operate as a basic alarm when the vision module is unavailable. & Maintain security even if the CAM fails. & High & State-machine review \\
        R6 & Provide a debug/configuration channel: native USB (USB-Serial/JTAG) plus a UART0 header (J1). & Allow setup, diagnostics, and logging. & Medium & Interface test \\
        R7 & Recover from transient UART errors through retry and timeout. & Improve communication robustness. & Medium & Protocol review \\
        R8 & Operate from a 5~V USB supply within standard current limits. & Simplify deployment and avoid overload. & Medium & Power budget analysis \\
        \bottomrule
    \end{tabular}
\end{table}

% -----------------------------------------------------------------------------
\section{Traceability matrix}
% -----------------------------------------------------------------------------

Table~\ref{tab:traceability} maps each requirement to the sections of this note
that address it and the planned verification method.

\begin{table}[H]
    \centering
    \caption{Requirements traceability matrix.}
    \label{tab:traceability}
    \begin{tabular}{>{\raggedright\arraybackslash}p{1.0cm} >{\raggedright\arraybackslash}p{4.4cm} >{\raggedright\arraybackslash}p{5.4cm}}
        \toprule
        \textbf{Req.} & \textbf{Addressed in} & \textbf{Verification activity} \\
        \midrule
        R1 & \S\ref{sec:pinout}, \S\ref{sec:statemachine}, \S\ref{sec:sketch} & GPIO input review; state coverage analysis. \\
        R2 & \S\ref{sec:pinout}, \S\ref{sec:statemachine}, \S\ref{sec:sketch} & GPIO input review; state coverage analysis. \\
        R3 & \S\ref{sec:uart}, \S\ref{sec:statemachine} & Protocol inspection; state-transition review. \\
        R4 & \S\ref{sec:statemachine}, \S\ref{sec:electrical} & Alarm-path review; output-drive analysis. \\
        R5 & \S\ref{sec:statemachine} (cam\_available flag) & State-machine review; CAM-failure scenario. \\
        R6 & \S\ref{sec:pinout}, \S\ref{sec:uart} & Native-USB and UART0-header interface review. \\
        R7 & \S\ref{sec:uart} (timeout/retry rules) & Protocol robustness analysis. \\
        R8 & \S\ref{sec:electrical} & Analytical power budget. \\
        \bottomrule
    \end{tabular}
\end{table}

% -----------------------------------------------------------------------------
\section{External interfaces}
% -----------------------------------------------------------------------------
\label{sec:interfaces}

Figure~\ref{fig:appnode-block} shows the controller node and its surrounding
interfaces.

\begin{figure}[H]
    \centering
    \begin{tikzpicture}[
        node distance=1.4cm and 2.0cm,
        >=Stealth
    ]
        \node[appnode] (app) {\textbf{Application Node}\\ESP32-C3\\Controller design};

        \node[io=nodegreen, left=2.6cm of app, yshift=1.0cm] (door) {Door contact\\IO4};
        \node[io=nodegreen, left=2.6cm of app, yshift=-1.0cm] (pir) {PIR motion\\IO5};

        \node[io=nodered, right=2.6cm of app, yshift=1.0cm] (led) {Alarm LED (D5)\\IO6};
        \node[io=nodered, right=2.6cm of app, yshift=-1.0cm] (buzz) {Buzzer\\IO10};

        \node[io=nodeblue, above=1.6cm of app] (cam) {ESP32-CAM\\UART1 IO0/IO1};

        \node[io=nodegray, below=1.6cm of app] (host) {Host: native USB\\(IO18/19) ; UART0 hdr J1};

        \draw[bus, nodegreen] (door.east) -- ++(0.6,0) |- node[above, pos=0.75, font=\scriptsize\sffamily]{event} (app.west);
        \draw[bus, nodegreen] (pir.east)  -- ++(0.6,0) |- node[below, pos=0.75, font=\scriptsize\sffamily]{event} (app.west);

        \draw[bus, nodered] (app.east) -- ++(0.6,0) |- node[above, pos=0.75, font=\scriptsize\sffamily]{drive} (led.west);
        \draw[bus, nodered] (app.east) -- ++(0.6,0) |- node[below, pos=0.75, font=\scriptsize\sffamily]{drive} (buzz.west);

        \draw[databus, nodeblue] (app.north) -- node[right, font=\scriptsize\sffamily]{115200 baud} (cam.south);

        \draw[databus, nodegray] (app.south) -- node[right, font=\scriptsize\sffamily]{USB-CDC / config / logs} (host.north);
    \end{tikzpicture}
    \caption{Application Node block diagram and external interfaces.}
    \label{fig:appnode-block}
\end{figure}

% -----------------------------------------------------------------------------
\subsection{Pinout}
\label{sec:pinout}
% -----------------------------------------------------------------------------

Table~\ref{tab:pinout} lists the controller pins used by the application node.

\begin{table}[H]
    \centering
    \caption{Application Node pin assignment.}
    \label{tab:pinout}
    \begin{tabular}{>{\raggedright\arraybackslash}p{2.7cm} c c >{\raggedright\arraybackslash}p{2.2cm} >{\raggedright\arraybackslash}p{5.2cm}}
        \toprule
        \textbf{Signal} & \textbf{Pin} & \textbf{Dir.} & \textbf{Function} & \textbf{Electrical notes} \\
        \midrule
        DOOR\_IN & IO4 & Input & Door contact state & Logic-level input; clamp/RC debounce network on board. \\
        PIR\_IN & IO5 & Input & PIR motion detect & PIR powered from 5~V; signal reaches IO5 via clamp/divider; edge or polled. \\
        ALARM\_LED & IO6 & Output & Alarm LED drive & Drives D5 via R15 (330~$\Omega$) series resistor. \\
        BUZZER\_DRV & IO10 & Output & Buzzer MOSFET gate & Drives Q1 (DN2302S) low-side switch via R12; 5~V buzzer load (LS1). \\
        CAM\_TX & IO1 & Output & UART1 TX to ESP32-CAM & 3.3~V, 115200~baud, via R21 + U5; no flow control. \\
        CAM\_RX & IO0 & Input & UART1 RX from ESP32-CAM & 3.3~V, 115200~baud, via R20 + U5; no flow control. \\
        USB\_TX & IO21 & Output & UART0 TX (debug header) & Wired direct to J1 (pin~2); not through U5. \\
        USB\_RX & IO20 & Input & UART0 RX (debug header) & Wired direct to J1 (pin~3); not through U5. \\
        USB\_D & IO18/19 & I/O & Native USB (D$-$/D$+$) & USB-Serial/JTAG to J2 via R3/R4 (22~$\Omega$) + U2 ESD; programming/CDC. \\
        3V3 & --- & Power & Logic supply rail & AP2112K-3.3 LDO (U1) output; feeds C3 + U5 only. \\
        VBUS & --- & Power & 5~V USB input & Over-current protected by PTC fuse F1; TPS2553 (U4) gates CAM\_5V only. \\
        GND & --- & Power & Common ground & Single-point/star grounding per PCB review. \\
        \bottomrule
    \end{tabular}
\end{table}

% -----------------------------------------------------------------------------
\subsection{UART interface parameters}
% -----------------------------------------------------------------------------

\begin{table}[H]
    \centering
    \caption{UART parameters for the ESP32-CAM link.}
    \begin{tabular}{@{}ll@{}}
        \toprule
        \textbf{Parameter} & \textbf{Value} \\
        \midrule
        Controller port & UART1 (IO0=RX / IO1=TX, via U5 isolation switch) \\
        Baud rate & 115200 \\
        Data bits & 8 \\
        Parity & None \\
        Stop bits & 1 \\
        Flow control & None \\
        Frame format & Binary header/length/ID/payload/checksum \\
        \bottomrule
    \end{tabular}
\end{table}

% -----------------------------------------------------------------------------
\subsection{Vision approach (open design decision)}
\label{sec:vision}
% -----------------------------------------------------------------------------

\textbf{This is a deliberately open, design-stage decision.}  The application
node treats the ESP32-CAM as a black box that returns a face-coverage result
code over UART (see the protocol in \S\ref{sec:uart}), but \emph{how} that
result is computed is not yet settled.  A key constraint is that a full
object-detection model (e.g.\ YOLO) does \textbf{not} fit on the ESP32-CAM: the
OV2640-based module is heavily constrained in RAM, flash, and compute.  Three
candidate approaches are under evaluation, each with different trade-offs:

\begin{description}[leftmargin=1.4cm, style=nextline]
    \item[(a) Tiny on-device classifier.] A small quantized classifier
        (ESP-DL or TFLite-Micro) running on the ESP32-CAM, performing a
        coarse \emph{face-present} / \emph{face-covered} judgement on small,
        downscaled frames.  \textit{Trade-off:} fits entirely on-device and
        keeps the architecture single-tier, but offers only modest accuracy and
        limited robustness to pose, lighting, and occlusion variety.
    \item[(b) Off-device inference (two-tier).] The CAM captures a frame and
        streams it over Wi-Fi to a host or edge device running a full model
        (e.g.\ YOLO or a stronger classifier), which returns the verdict.
        \textit{Trade-off:} full accuracy and model flexibility, but requires an
        always-available host and changes the system from one self-contained
        board into a \textbf{two-tier} architecture (latency, networking, and
        availability dependencies).
    \item[(c) Built-in face detection as a coverage proxy.] Use only ESP-DL's
        built-in face-detection primitive and treat ``no detectable face'' as a
        proxy for a covered face.  \textit{Trade-off:} simplest to implement and
        cheapest on-device, but the weakest semantically --- it cannot reliably
        distinguish a \emph{covered face} from \emph{no person present}, which
        risks both false alarms and missed detections.
\end{description}

The choice among (a), (b), and (c) is intentionally left open at this stage; it
should be resolved with an explicit memory/latency budget before firmware is
written.  Assumption~A7 references this open decision rather than asserting any
particular on-device method as settled.

% -----------------------------------------------------------------------------
\section{Electrical design summary}
\label{sec:electrical}
% -----------------------------------------------------------------------------

\subsection{Key components}

Table~\ref{tab:bom} lists the principal devices and their roles; the full
passive network and exact part numbers are in the schematic and the project BOM
(\texttt{assets/SecurityNode.BomDoc}).

\begin{table}[H]
    \centering
    \caption{Key components (designator $\rightarrow$ part $\rightarrow$ role).}
    \label{tab:bom}
    \begin{tabular}{@{}l >{\raggedright\arraybackslash}p{4.4cm} >{\raggedright\arraybackslash}p{6.2cm}@{}}
        \toprule
        \textbf{Ref.} & \textbf{Part} & \textbf{Role} \\
        \midrule
        U1 & AP2112K-3.3TRG1 & 3.3~V / 600~mA LDO (logic rail). \\
        U2 & USBLC6-2P6 & USB D+/D$-$ ESD protection. \\
        U3 & ESP32-C3-WROOM-02-N4 & Controller / application node. \\
        U4 & TPS2553DBVR & ESP32-CAM power gate (adjustable current limit). \\
        U5 & SN74LVC2G66DCTR & CAM-presence-gated UART1 isolation switch. \\
        Q1 & DN2302S & N-MOSFET low-side buzzer driver. \\
        LS1 & KPEG242-5V & Buzzer (5~V). \\
        D5 & XL-2012SURC & Red 0805 alarm LED. \\
        D1 & SMF5.0CA & VBUS input TVS clamp. \\
        F1 & Littelfuse 1206L075/16V & PTC resettable fuse (input over-current). \\
        FB1 & HCB1608KF-600T20 & 60~$\Omega$ ferrite bead (input EMI filter). \\
        J2 & KH-MINI-SMT-5P (Mini-USB~B) & 5~V input + native-USB data. \\
        J3 & ESP32-CAM (AI-Thinker) & Vision-module mezzanine connector. \\
        J1 / J7 & Pin headers & ESP32-C3 / ESP32-CAM programming \& debug. \\
        \bottomrule
    \end{tabular}
\end{table}

\subsection{Power architecture}

The board receives 5~V (VBUS) from a Mini-USB connector (J2).  The input chain
is: VBUS $\rightarrow$ \textbf{F1} (PTC resettable fuse; whole-board over-current
protection) $\rightarrow$ \textbf{D1} (input TVS clamp) with \textbf{C1} bulk
capacitor $\rightarrow$ \textbf{FB1} (ferrite bead) $\rightarrow$ the
\textbf{5~V rail}.  The 5~V rail then feeds, \emph{in parallel}, the
\textbf{U1} (AP2112K-3.3) LDO and the \textbf{U4} (TPS2553) CAM power gate, as
well as the buzzer (LS1) and the PIR supply.

The \textbf{3.3~V rail} (U1 output) feeds \textbf{only the ESP32-C3 (U3) and the
U5 switch} plus logic pull-ups.  The buzzer and PIR run directly on the
\textbf{5~V rail}.  The ESP32-CAM runs on \texttt{CAM\_5V} --- the gated output
of U4 --- together with its own internal \texttt{CAM\_3V3} regulator output; the
on-board LDO does not power the CAM.  ESD protection on the USB data lines is
provided by U2 (USBLC6-2P6) with series 22~$\Omega$ resistors; input-line TVS
clamping uses SMF5.0CA devices.  U4 does \emph{not} distribute power board-wide
--- whole-board USB over-current protection is the job of F1.

\subsection{Camera power gate (U4) and UART isolation switch (U5)}
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

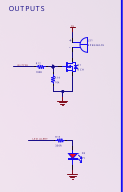
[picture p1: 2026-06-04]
docs/presentation/images/schematic_blocks/outputs.png

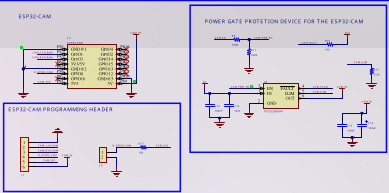
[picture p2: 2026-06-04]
assets/Schematic Blocks/esp32cam.png

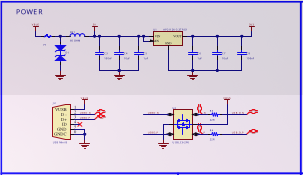
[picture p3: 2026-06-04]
docs/presentation/images/schematic_blocks/power.png

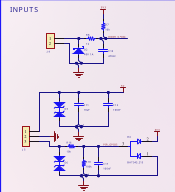
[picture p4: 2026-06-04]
assets/Schematic Blocks/inputs.png

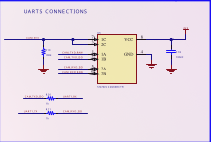
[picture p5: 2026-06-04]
assets/Schematic Blocks/uarts.png

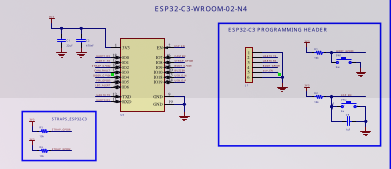
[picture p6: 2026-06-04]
docs/presentation/images/schematic_blocks/esp32c3.png

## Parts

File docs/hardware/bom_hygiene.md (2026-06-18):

# BOM Hygiene Checklist — SecurityNode

> **Design-stage cleanup list — not yet fabricated.** The board is drawn in Altium but
> not built. This is a punch-list of data-quality problems in the Altium LiveBOM
> (`assets/SecurityNode.BomDoc`) that should be resolved **before any real fabrication
> or quoting**, plus the open hardware-confirmation items that still need to be checked
> against the Altium source. Each item below is verified against
> `assets/SecurityNode.BomDoc`; the schematic netlist (`assets/SecurityNode.pdf`) is
> authoritative on any disagreement. See `docs/application_node/DESIGN-AUDIT.md` §7 for
> the broader audit context.
>
> Nothing here changes the *design* — these are catalog/metadata defects and unresolved
> per-designator assignments, not topology errors.

---

## 1. Data-quality defects to correct in the BOM

- [ ] **SMF5.0CA TVS mislabeled "TVS 12V".** The user comment / `Comment` field reads
  `TVS 12V`, but the part is a **5 V** bidirectional TVS (the LCSC description itself
  says *"… Bidirectional **5V** SOD-123FL ESD and Surge Protection"*). Correct the
  comment to a 5 V label (e.g. `TVS 5V`) so the value column does not contradict the
  part. *(This is the same part family used at the VBUS input and on the PIR line — see
  the open diode-split item in §2.)*

- [ ] **100 nF capacitor: description says 0201, footprint is 0603.** The `Description`
  reads *"100nF ±20% 6.3V Ceramic Capacitor X5R **0201**"* while `Footprint=0603_cap`.
  The placed footprint (0603) is what the board uses; fix the description so the package
  size matches the footprint (0603), or re-confirm the intended package against the
  Altium source and make both fields agree.

- [ ] **F1 has a stray "YTL " prefix on the part number.** The manufacturer part number
  proper is `1206L075/16V` (Littelfuse Inc.), but the catalog item's design-item ID,
  library reference, and `Comment`/user-comment fields all carry `YTL 1206L075/16V`.
  Strip the stray `YTL ` prefix so the part is unambiguously the Littelfuse `1206L075/16V`
  PTC.

- [ ] **J2 (Mini-USB-B) lists the wrong manufacturer.** Manufacturer is given as
  `EDAC Inc.` while the part number is `KH-MINI-SMT-5P-Cu` — that MPN is a **Shenzhen
  Kinghelm** part (the LCSC datasheet link in the same record points to
  *Kinghelm KH-MINI-SMT-5P-Cu*, C2688795). Correct the manufacturer to **Kinghelm**
  (keep the MPN and supplier part number, which are already correct).

- [ ] **Non-standard / corrupted manufacturer-part-number keys.** Several parts use keys
  that do **not** match the standard `Manufacturer` / `Manufacturer Part Number` columns
  and therefore drop out of a standard BOM export. Normalize these to the standard keys:
  - [ ] `MF=` / `MP=` instead of `Manufacturer` / `Manufacturer Part Number` on:
    **U1 (AP2112K-3.3TRG1)**, **U4 (TPS2553DBVR)**, **U5 (SN74LVC2G66DCTR)**,
    the **ESP32-CAM** module, **D4 (BAT54S)**, and **LS1 (KPEG242-5V)** (the latter
    also has an **empty** `MF=` manufacturer field to fill in).
  - [ ] **U2 (USBLC6-2P6)** uses corrupted **`Manufacturer Pad Number=`** and
    **`Supplier Pad Number=`** keys (should be **"Part Number"**, not "Pad Number");
    these will silently disappear from a standard export. Rename to
    `Manufacturer Part Number` / `Supplier Part Number`.
  - [ ] **F1** uses `Supplier=` / `Supplier Part Number=` (no trailing `1`) where most
    rows use `Supplier 1` / `Supplier Part Number 1`. Make the supplier keys consistent
    so all rows export under the same columns.

- [ ] **YAGEO 100 k resistor links to the wrong datasheet.** The 100 k part
  (`RC0603FR-07100KL`, YAGEO) has a `ComponentLink1URL` that points to an **84.5 Ω**
  part (`…CR0603FA84R5G…`). Repoint the datasheet/product link to the correct
  100 kΩ part so anyone cross-checking the component lands on the right datasheet.

- [ ] **The BOM has no Designator column — it is a value catalog.** Every row is a
  *value/part class* (e.g. "10k 1/10W", "1k 1/10W", "100nF 6.3V"), with **no R#/C#/D#
  designators** mapping a board reference to a specific MPN. Before fabrication or
  quoting, add a **designator → MPN assignment** (a real per-reference BOM), so that
  each placed component on the PCB resolves to exactly one purchasable part. This is a
  prerequisite for the per-designator confirmation items in §2.

---

## 2. Open hardware-confirmation items (to be confirmed against the Altium source)

These are **not** known errors — they are details that the BOM/schematic exports do not
pin down unambiguously, and that must be confirmed against the Altium source (a high-res
schematic render or the project files) before the BOM is finalized.

- [ ] **D1 / D3 / D6 TVS-vs-Schottky designator split — to be confirmed.** The BOM holds
  exactly **2× SMF5.0CA** (TVS 5 V) and **2× PSBD1DF40V1H** (Schottky 40 V / 1 A). Only
  **D2 = Schottky** (door clamp, schematic-confirmed) and **D5 = LED** (XL-2012SURC) are
  **certain**; **D4 = BAT54S** (PIR clamp) is also certain. The remaining split among
  **D1 / D3 / D6** (which is the VBUS input TVS, which is the 5 V-rail Schottky, which is
  the PIR-line TVS) is **inferred from topology only** — the per-designator package is not
  printed in the BOM. Confirm the exact D1/D3/D6 assignment against the Altium source
  before publishing the diode table. *(to be confirmed)*

- [ ] **Per-designator R / C → MPN assignment — to be confirmed.** Because the BOM is a
  value catalog (§1), the one-to-one mapping of each resistor/capacitor reference to its
  exact MPN is inferred from value class plus net context. The load-bearing **values** are
  confirmed (e.g. R3/R4 = 22 R, R8/R20/R21 = 1 k, R9/R12 = 100 R, 10 k pull-ups,
  R11/R18/R19 = 100 k, R13 = 21k5, R15 = 330 R), but the precise split among same-value
  parts (e.g. *which* 100 nF cap is *which* reference) is inference. Confirm each
  designator's MPN against the Altium source, or add a designator column to the BOM so the
  mapping is explicit. *(to be confirmed)*

---

*Source of truth: `assets/SecurityNode.pdf` (schematic netlist, authoritative on
disagreement) and `assets/SecurityNode.BomDoc` (Altium LiveBOM). Cleanup items in §1 are
metadata/data-quality fixes that do not alter the design; items in §2 are unresolved
assignments to confirm before fabrication.*

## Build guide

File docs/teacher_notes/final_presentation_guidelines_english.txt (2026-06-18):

Suggested structure and expected elements for the final presentations (Submit the deliverable as a PDF)

For the final presentations of the course projects, it is suggested that the presentation be organized in a clear, brief, and evidence-oriented manner. Each presentation will last approximately [duration], followed by a short period for questions or transition.

The presentation should show not only the final result, but also the design process, the technical decisions made, and the evidence produced during the development of the project.

The following structure is recommended:

1. Project title, name, and email address

Include the project title, the student's full name, and institutional email address.

It is also recommended to begin with a brief phrase that allows the audience to quickly understand the purpose of the project.

2. Description in natural language

Explain the project in a simple way, as if presenting it to someone who is not familiar with the technical details.

The description should answer questions such as:

What problem, need, or application does the project address?
Who could use this product or system?
What is its main function?
What behavior is expected from the system?

3. Block diagram

Present the general architecture of the system using a block diagram.

The diagram should make it possible to identify the main modules, for example:

Power supply.
Microcontroller or control unit.
Sensors.
Actuators.
Communication interfaces.
Display, indicators, or interaction elements.
Power stages, conditioning stages, or protection stages, if applicable.

In this part, the student is expected to explain how the blocks are related to one another and what the function of each one is.

4. Power tree

Present the power tree of the project, indicating how energy is distributed within the system.

It is recommended to include:

Main power supply.
Voltage levels used.
Regulators or converters used.
Blocks powered by each voltage level.
Estimated currents or approximate power consumption, if available.
Protection considerations, connectors, batteries, chargers, or switches, if applicable.

This section is important to justify that the electronic design adequately considers the energy requirements of the system.

5. Product proof of concept

Show the proof of concept developed during the course.

This section should provide evidence that the idea was explored, validated, or partially implemented before or during the PCB design.

It may include:

Breadboard assembly.
Testing with development modules.
Preliminary code.
Testing of sensors, actuators, or communication.
Photographs or videos of the operation.
Basic measurements.
Partial validations of a critical function.

It is recommended to explain what was verified through the proof of concept and what limitations were found.

6. Schematic diagram

Present the circuit schematic, highlighting the most important parts.

It is not necessary to explain every connection, but the main decisions should be justified:

Selection of the microcontroller, sensors, actuators, or modules.
Voltage regulators.
Programming or communication interfaces.
Pull-up or pull-down resistors.
Voltage dividers.
Protections.
Connectors.
Power stages or signal conditioning stages.

The presentation should show that the schematic was built based on well-reasoned design decisions.

7. PCB

Present the PCB design and explain the criteria used in its construction.

It is recommended to mention:

Size and shape of the board.
Component placement.
Functional organization of the PCB.
Critical traces.
Separation between power signals, digital signals, analog signals, or communication signals.
Ground or power planes.
Manufacturing and assembly considerations.
Connectors, test points, or interaction elements.

The idea is to explain why the PCB was organized in that way and what aspects were taken into account to make it manufacturable and functional.

8. 3D render of the PCB

Show the 3D render of the board as visual support to understand the final product.

In this section, you may comment on:

General appearance of the board.
Physical location of connectors, buttons, indicators, or sensors.
Relationship between the PCB and a possible enclosure, mounting system, or final product.
Possible assembly or mechanical integration difficulties.

9. Closing

End with a brief reflection on the current state of the project and the learning obtained.

It is recommended to answer:

What was the greatest technical difficulty?
Which part of the design was best resolved?
What aspect should be improved in a next version?
What is still needed to manufacture, assemble, or fully validate the board?
What did I learn about electronic design during the development of the project?

Not all projects are expected to be completely finished, but each presentation is expected to clearly show the progress achieved, the decisions made, and the evidence available.

10. References

Include a final slide with the references used during the design.

These may include:

Component datasheets.
Application notes.
Manufacturer design guides.
Documentation for modules, sensors, or microcontrollers.
Repositories, examples, or libraries used.
Standards, technical tutorials, or academic resources consulted.

The references should make it possible to identify the technical sources that supported the design decisions.

General recommendations

The presentation should be concrete, visual, and evidence-based. It is preferable to show diagrams, screenshots, photographs, measurements, renders, or test results instead of using slides with too much text.

Each student should be prepared to explain their design from an electronic point of view, including the system architecture, power distribution, proof of concept, schematic, PCB, 3D render, and main technical references used.

The presentation should focus on the design decisions and the evidence produced during the course.

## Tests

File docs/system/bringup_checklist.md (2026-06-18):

# Bring-Up Checklist — SecurityNode

> **Status:** Design-stage / not-yet-fabricated board. This checklist describes the
> *planned* bring-up procedure verified against the schematic netlist. Pin numbers,
> designators, and chip roles below reflect the schematic ground truth.

## Pre-Power Checks

- [ ] Visually inspect PCB for solder bridges, missing components, or component orientation issues.
- [ ] Verify USBLC6-2P6 (U2) ESD array and input TVS diode (D1, SMF5.0CA) are correctly placed near USB connector J2.
- [ ] Confirm AP2112K-3.3TRG1 LDO (U1) and TPS2553DBVR CAM power gate (U4) orientations match the PCB silkscreen.
- [ ] Verify PTC resettable fuse F1 (Littelfuse 1206L075) is installed in the VBUS input path (whole-board over-current protection).
- [ ] Check that ferrite bead FB1 is installed between USB 5V and the main power rail.
- [ ] Verify decoupling capacitors are populated (C1 = 22µF VBUS bulk; per-designator value map is to be confirmed against the Altium source).

## Power-Up Sequence

- [ ] Connect a current-limited bench supply (5V, 500mA limit) to J2 or inject 5V at the test points.
- [ ] Measure 5V rail at the output of FB1 (should be ~4.9–5.0V). Note: the 5V rail feeds U1 (LDO) and U4 (CAM gate) in parallel, plus LS1 buzzer and J5 PIR VCC.
- [ ] Measure 3.3V rail at the output of AP2112K (U1): should be 3.28–3.32V. (The 3.3V rail feeds only U3 / the C3 and U5 plus logic pull-ups.)
- [ ] Check 3.3V ripple with an oscilloscope (< 50mVpp recommended).
- [ ] Confirm U4 (TPS2553) CAM_5V output is OFF by default at power-up — R11 100k pulldown holds CAM_EN low until the C3 drives IO7 (CAM_5V test is in the ESP32-CAM Interface section).

## Programming Interface

The ESP32-C3 (U3) is flashed over its **native USB** (USB-Serial/JTAG) on IO18/IO19 via J2 — there is **no** USB-UART bridge chip (no CP210x) on this board. J1 is an alternate UART0 debug/flash header (GPIO20/GPIO21 + BOOT/EN).

- [ ] Connect USB cable to J2.
- [ ] Verify PC enumerates the ESP32-C3's **native USB CDC (USB-Serial/JTAG)** device — NOT a CP210x or other USB-UART bridge.
- [ ] If using the alternate UART0 path instead, connect to header J1 (1=GND, 2=UART0_TX/GPIO21, 3=UART0_RX/GPIO20, 4=BOOT_GPIO9, 5=ESP_EN, 6=GND).
- [ ] Enter bootloader mode (manual): hold SW1 (BOOT, GPIO9), press SW2 (EN/reset), release SW2, then release SW1. (Native USB normally auto-resets into the bootloader without this.)
- [ ] Flash a simple "Hello World" / blink sketch to the ESP32-C3 (U3).

## Peripheral Tests

### Alarm Output
- [ ] Write a test sketch to toggle **IO10 (BUZZER)** — drives Q1 (DN2302S) gate via R12 100R.
- [ ] Verify buzzer (LS1, on 5V rail) sounds when IO10 is driven HIGH.
- [ ] Write a test sketch to toggle **IO6 (LED_ALERT)** — drives D5 (XL-2012SURC red LED) via R15 330R.
- [ ] Verify alarm LED (D5) lights when IO6 is driven HIGH.

### Sensor Inputs
- [ ] Connect a door contact switch to J4.
- [ ] Toggle the switch and verify the ESP32-C3 reads the correct logic level on **IO4 (DOOR_GPIO4)**. (Active polarity of the on-board debounce/clamp network — R7/R8/C10 + D2 Schottky — is to be confirmed against the schematic.)
- [ ] Connect a PIR sensor to J5 (PIR VCC on J5 is hard-wired to the **5V rail**).
- [ ] Verify PIR output triggers **IO5 (PIR_GPIO5)**. (Signal reaches IO5 through a clamp/conditioning network — D4 BAT54S + 100k bias resistors; exact polarity to be confirmed against the schematic.)

### ESP32-CAM Interface
- [ ] Seat ESP32-CAM module onto J3 connector.
- [ ] **CAM power-gate test:** drive **IO7 (CAM_EN)** HIGH and verify **CAM_5V** appears at U4 (TPS2553) output (J3 P$9 / J7 pin6). With IO7 LOW, confirm CAM_5V is OFF (R11 100k default-OFF).
- [ ] Verify the CAM module's own **CAM_3V3** rail comes up (the CAM's internal regulator output, J3 P$8) once CAM_5V is enabled.
- [ ] Force/simulate an over-current on the CAM branch and verify U4 asserts FAULT — confirm the C3 reads it on **IO3 (CAM_FAULT)** (R10 10k pull-up).
- [ ] Verify the UART1 link between ESP32-C3 and ESP32-CAM: C3 **IO0 = RX**, **IO1 = TX** (via R20/R21 1k and U5). Confirm with a logic analyzer. Note that U5 (SN74LVC2G66) auto-connects this link only when a powered CAM is seated (control tied to CAM_3V3) — verify continuity is present with the CAM powered and open with the CAM removed/off.
- [ ] Send a capture command from the ESP32-C3 and verify the CAM responds with status/ack.

## Communication Tests

- [ ] Test basic UART1 echo between ESP32-C3 (IO0=RX / IO1=TX) and ESP32-CAM over the U5-isolated link.
- [ ] Verify the U5 (SN74LVC2G66) **automatic presence gating**: with a powered CAM seated the UART1 link is connected; with the CAM absent/unpowered the link is isolated. U5 is NOT host/GPIO-selectable and is NOT a USB-to-UART routing mux.
- [ ] **Flash the ESP32-CAM out-of-band:** connect an external USB-UART adapter to header **J7** (6-pin: GND, CAM_TXD_RAW, CAM_RXD_RAW, B_GPIO0_CAM, CAM_3V3, CAM_5V) and fit the **J6** 2-pin CAM-GPIO0 boot jumper to enter the CAM bootloader. (No on-board USB path reaches the CAM; do NOT attempt to route the board's USB to the CAM.)

## Integration Test

> The event flow and vision/alarm behavior below describe the **proposed** firmware design
> (no firmware is committed yet — code directories hold only `.gitkeep`). Use as the planned
> acceptance test once firmware exists.

- [ ] Trigger a door-open event.
- [ ] Confirm ESP32-C3 requests image capture from ESP32-CAM.
- [ ] Confirm alarm sounds if CAM reports a covered face (simulate with test command if vision algorithm is not yet ready).
- [ ] Confirm alarm does NOT sound if CAM reports a visible face.
- [ ] Disconnect ESP32-CAM and verify basic alarm still functions (fallback mode).

## Notes / Issues

| Date | Issue | Resolution |
|---|---|---|
| | | |
| | | |

## Sign-Off

| Test Phase | Pass | Fail | N/A |
|---|---|---|-----|
| Pre-Power  | [ ]  | [ ]  | [ ] |
| Power-Up | [ ]  | [ ]  | [ ] |
| Programming| [ ]  | [ ]  | [ ] |
| Peripherals| [ ]  | [ ]  | [ ] |
| Integration| [ ]  | [ ]  | [ ] |

---

**Tester:** ________________________  **Date:** ________________________

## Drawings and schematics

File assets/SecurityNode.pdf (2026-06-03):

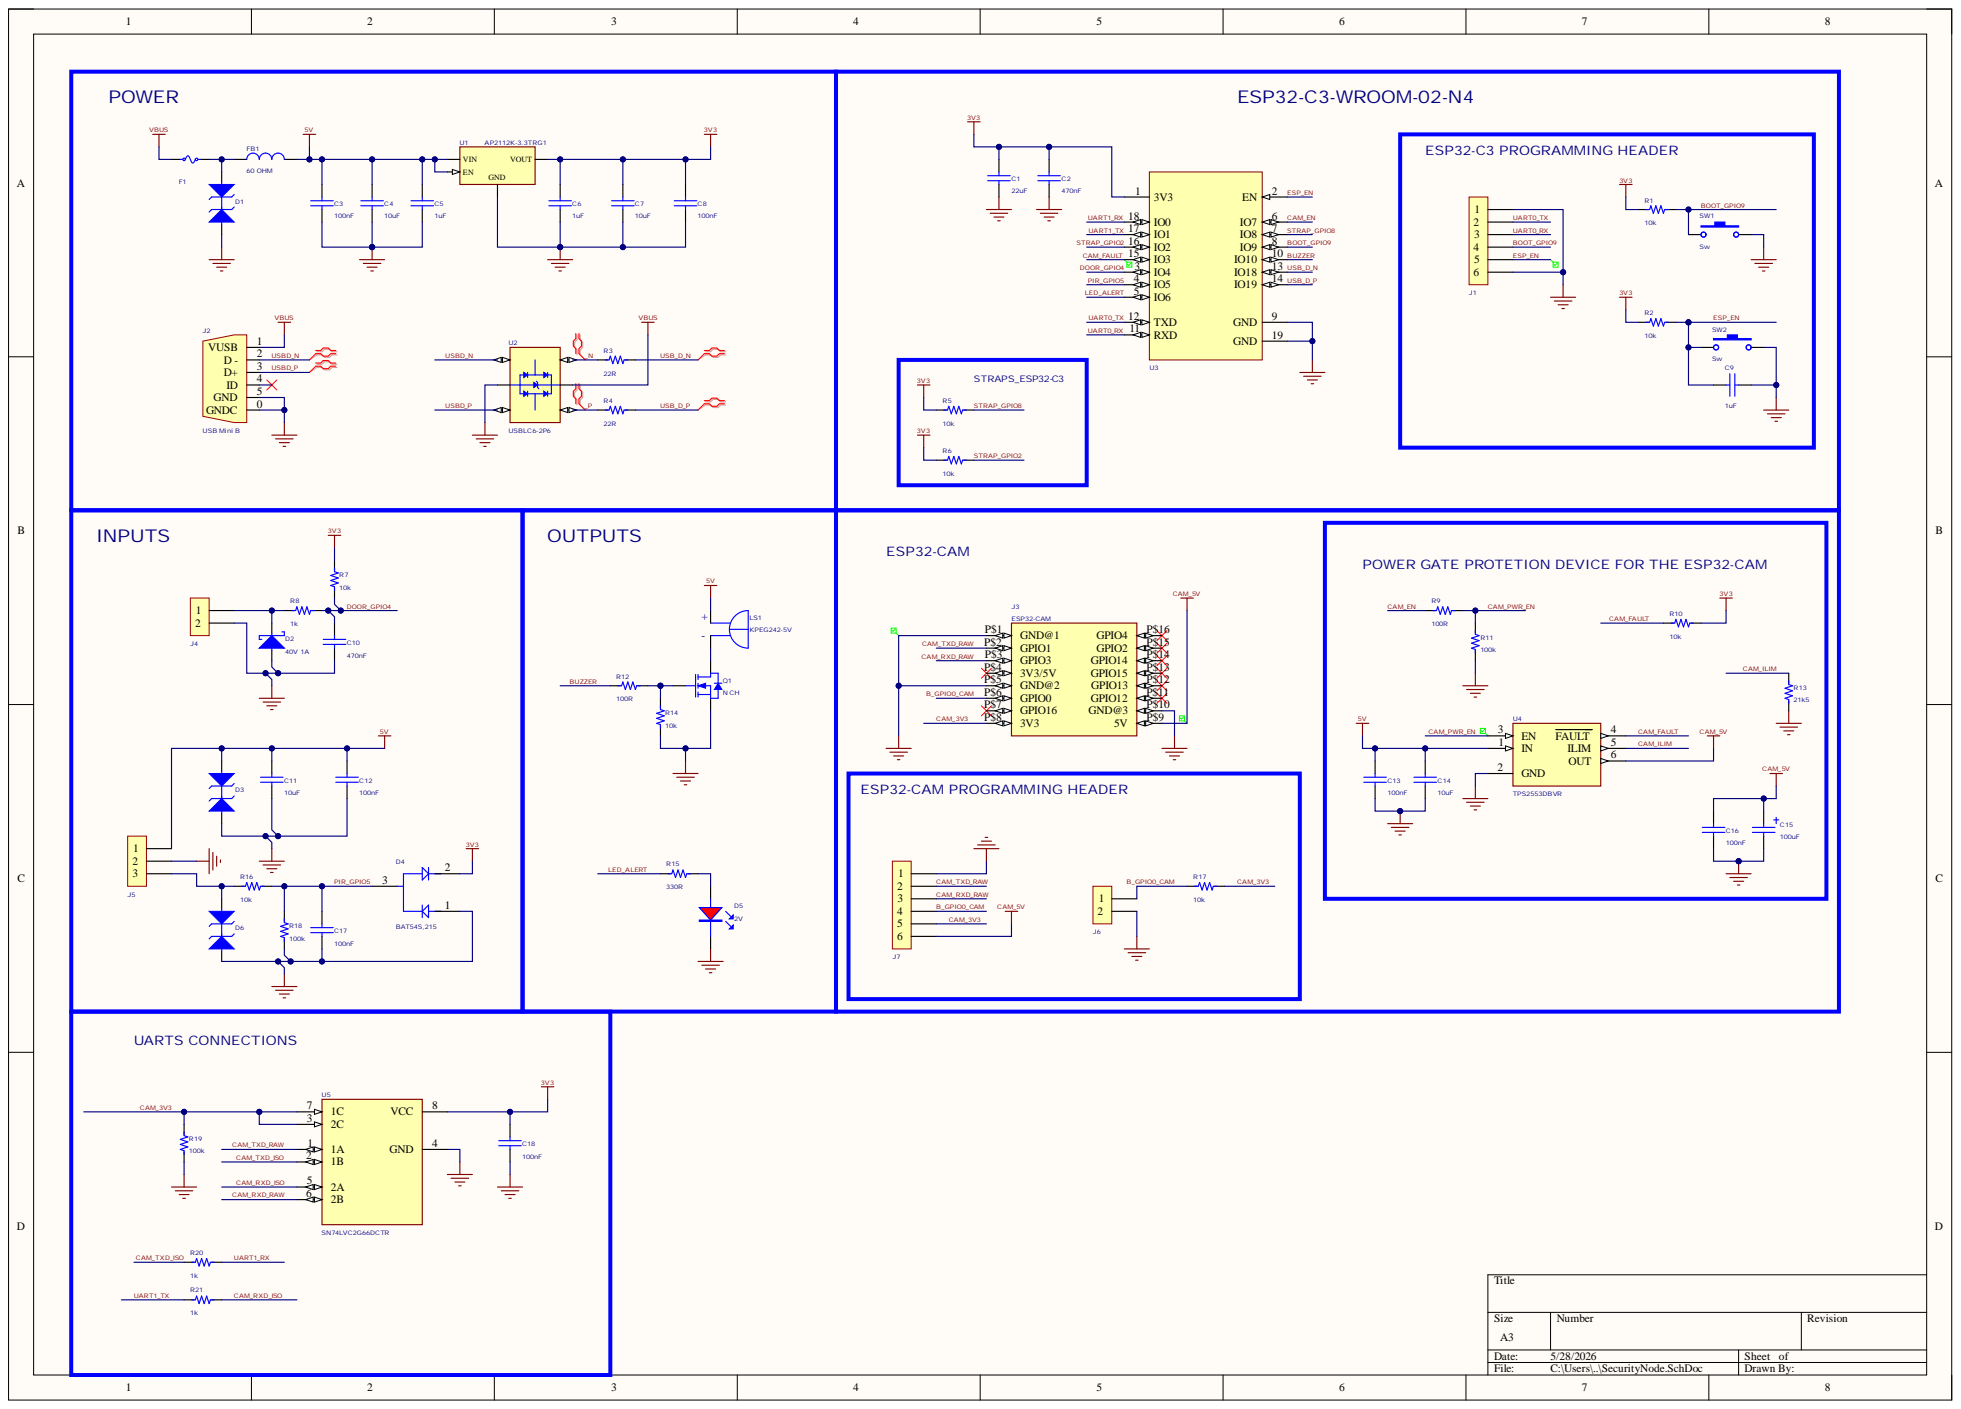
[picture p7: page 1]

POWER GATE PROTETION DEVICE FOR THE ESP32-CAM

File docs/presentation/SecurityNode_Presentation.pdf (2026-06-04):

PROYECTO FINAL DE DISEÑO ELECTRÓNICO

# SecurityNode

## Sistema de seguridad embebido con verificación visual de amenazas

## Jerónimo Vargas Orozco

jevargaso@unal.edu.co

# Descripción en lenguaje natural

Plataforma de seguridad embebida que detecta intrusiones físicas y las verifica con visión por computador, funcionando completamente en el borde sin depender de la nube.

### El Problema

Las alarmas tradicionales detectan eventos pero no indican qué los provocó. Mascotas, viento o usuarios autorizados generan la misma sirena que un intruso real.

### Usuarios

Propietarios de viviendas y pequeños negocios que requieren seguridad asequible, respetuosa con la privacidad y sin suscripciones ni almacenamiento en la nube.

### Función Principal

Sensores de puerta y PIR detectan intrusiones. Al activarse, el sistema captura una imagen y decide: amenaza real o falsa alarma.

### Comportamiento

Alarma ON: LED rojo + buzzer si rostro cubierto o timeout.
Alarma OFF: Se registra el evento y vuelve a reposo. Sin cámara: Opera como alarma básica.

# Diagrama de bloques

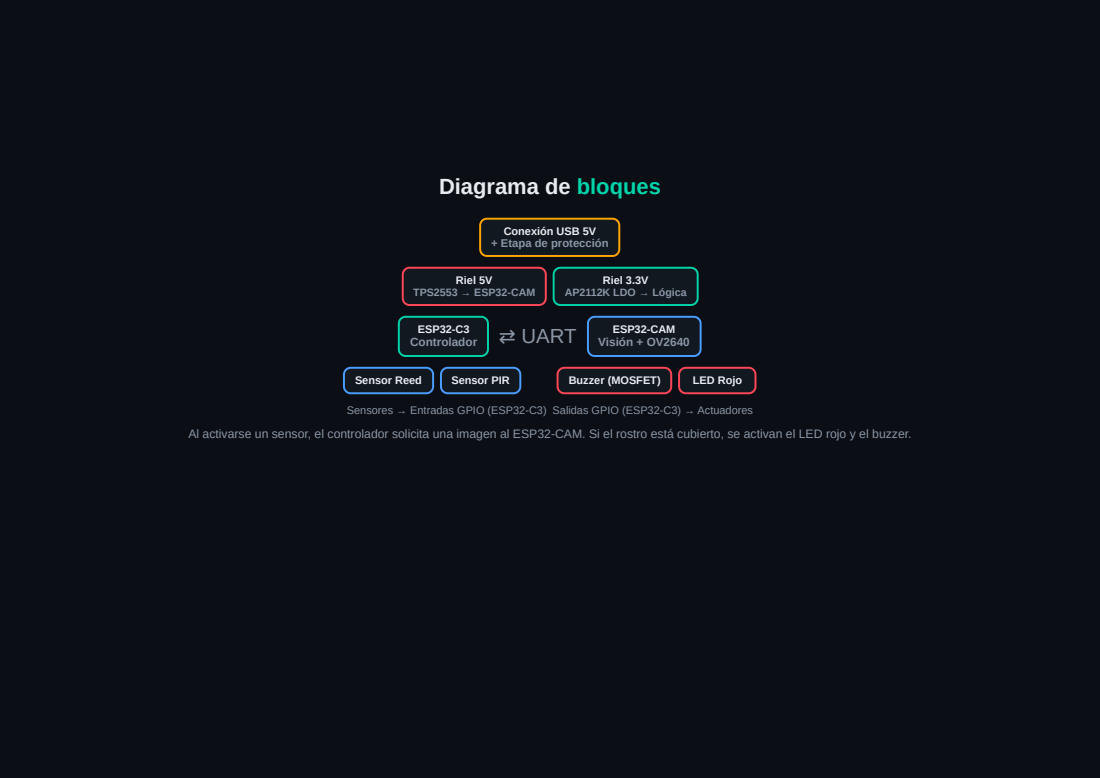
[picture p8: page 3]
Riel 5V TPS2553 → ESP32-CAM; Riel 3.3V AP2112K LDO → Lógica; ESP32-C3; Controlador; ⇄ UART; ESP32-CAM Visión + OV2640; Sensor Reed; Sensor PIR; Buzzer (MOSFET); LED Rojo

Conexión USB 5V
+ Etapa de protección

Sensores → Entradas GPIO (ESP32-C3) Salidas GPIO (ESP32-C3) → Actuadores

Al activarse un sensor, el controlador solicita una imagen al ESP32-CAM. Si el rostro está cubierto, se activan el LED rojo y el buzzer.

# Árbol de potencia

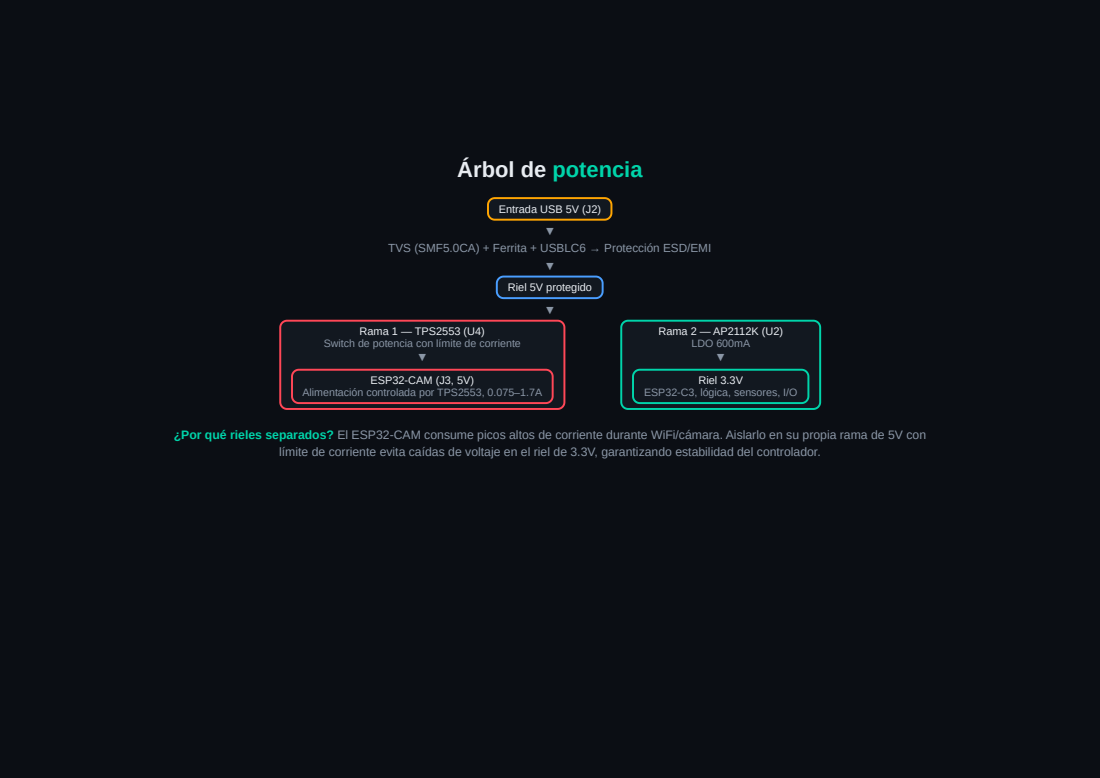
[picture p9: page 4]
Entrada USB 5V (J2); Riel 5V protegido; Rama 1 — TPS2553 (U4); ESP32-CAM (J3, 5V); Rama 2 — AP2112K (U2) LDO 600mA ▼; Riel 3.3V ESP32-C3, lógica, sensores, I/O

TVS (SMF5.0CA) + Ferrita + USBLC6 → Protección ESD/EMI

Switch de potencia con límite de corriente

Alimentación controlada por TPS2553, 0.075–1.7A

¿Por qué rieles separados? El ESP32-CAM consume picos altos de corriente durante WiFi/cámara. Aislarlo en su propia rama de 5V con

límite de corriente evita caídas de voltaje en el riel de 3.3V, garantizando estabilidad del controlador.

# Prueba de concepto

Prototipo en protoboard con ESP-WROOM-32, webcam de laptop y script Python con MediaPipe.

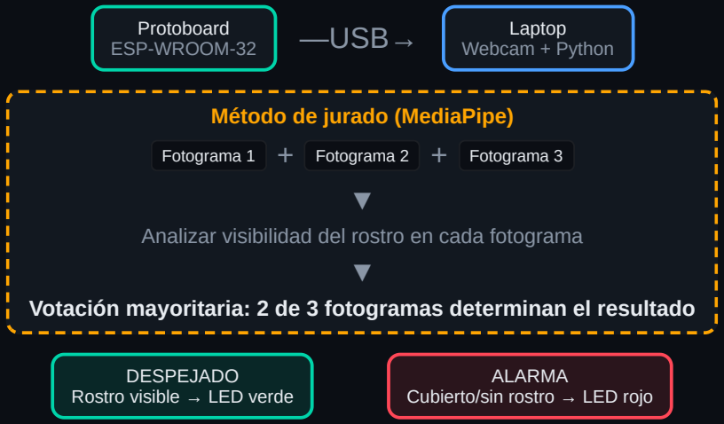
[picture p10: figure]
Protoboard; ESP-WROOM-32; —USB→; Laptop; Webcam + Python; Método de jurado (MediaPipe); Fotograma 1; Fotograma 2; Fotograma 3; DESPEJADO Rostro visible → LED verde; ALARMA Cubierto/sin rostro → LED rojo

Analizar visibilidad del rostro en cada fotograma

Votación mayoritaria: 2 de 3 fotogramas determinan el resultado

Validado: Lógica de sensores, simulación UART, algoritmo de decisión, control de LED. Limitaciones: Webcam de laptop ≠ OV2640; Python ≠ C++ embebido; sin PCB real; buzzer pendiente.

# Diagrama esquemático

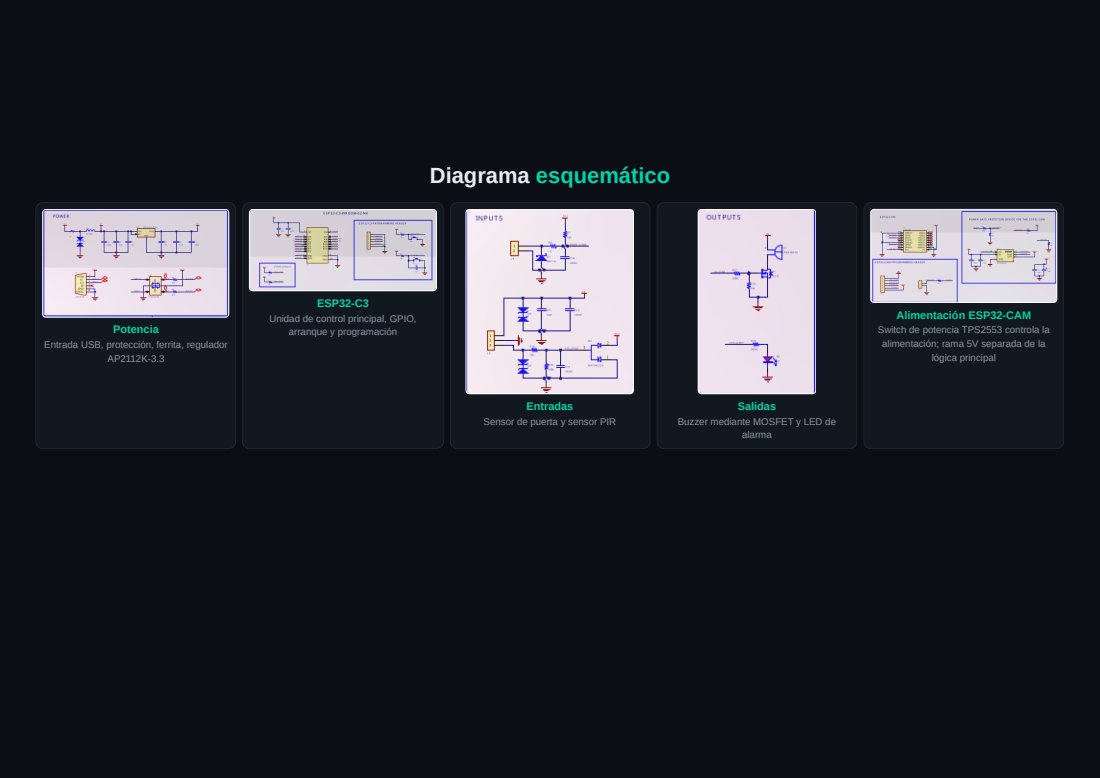
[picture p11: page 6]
Potencia; ESP32-C3; Entradas; Salidas; alarma; lógica principal

Unidad de control principal, GPIO,
arranque y programación

Alimentación ESP32-CAM
Switch de potencia TPS2553 controla la
alimentación; rama 5V separada de la

Entrada USB, protección, ferrita, regulador

Sensor de puerta y sensor PIR

Buzzer mediante MOSFET y LED de

# PCB

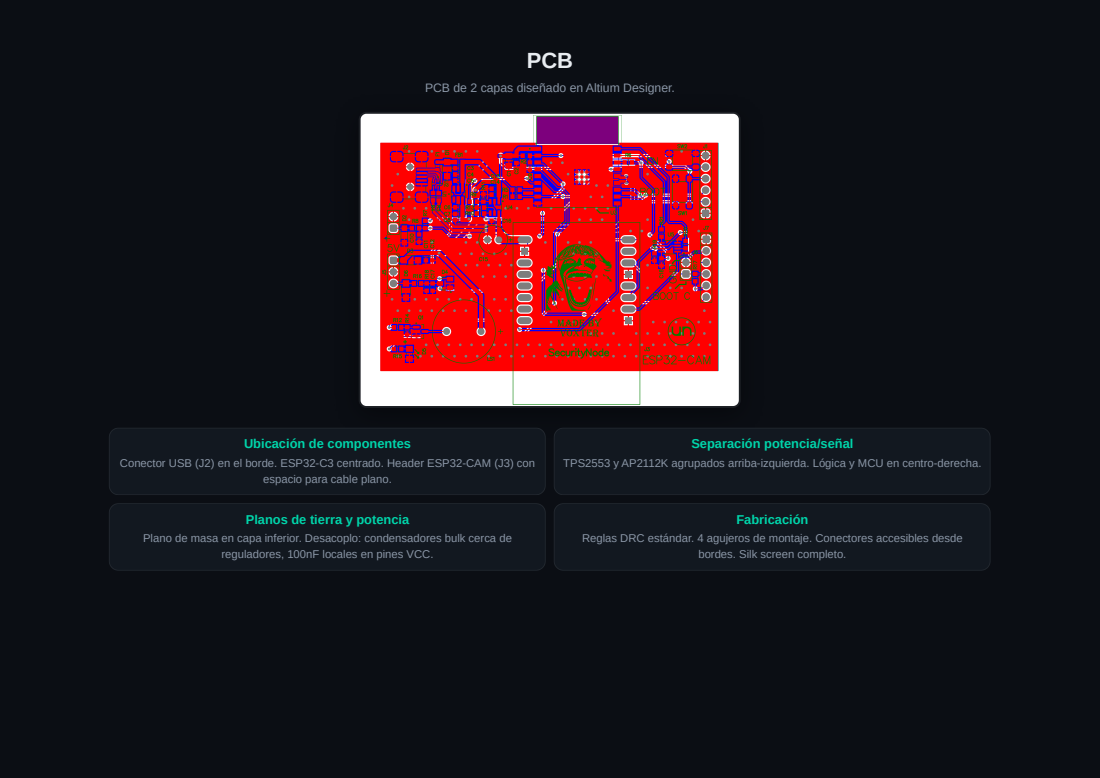
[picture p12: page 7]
Fabricación

PCB de 2 capas diseñado en Altium Designer.

Ubicación de componentes

Separación potencia/señal

Conector USB (J2) en el borde. ESP32-C3 centrado. Header ESP32-CAM (J3) con

TPS2553 y AP2112K agrupados arriba-izquierda. Lógica y MCU en centro-derecha.

espacio para cable plano.

Planos de tierra y potencia

Plano de masa en capa inferior. Desacoplo: condensadores bulk cerca de

Reglas DRC estándar. 4 agujeros de montaje. Conectores accesibles desde

reguladores, 100nF locales en pines VCC.

bordes. Silk screen completo.

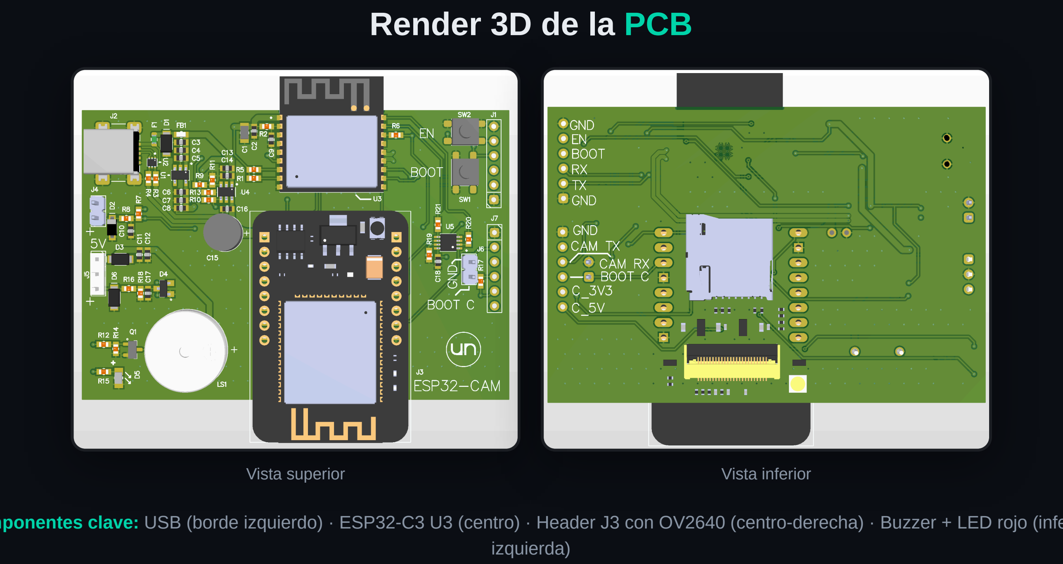
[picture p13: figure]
Render 3D de la PCB; Vista superior; Vista inferior; izquierda)

Componentes clave: USB (borde izquierdo) · ESP32-C3 U3 (centro) · Header J3 con OV2640 (centro-derecha) · Buzzer + LED rojo (inferior-
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

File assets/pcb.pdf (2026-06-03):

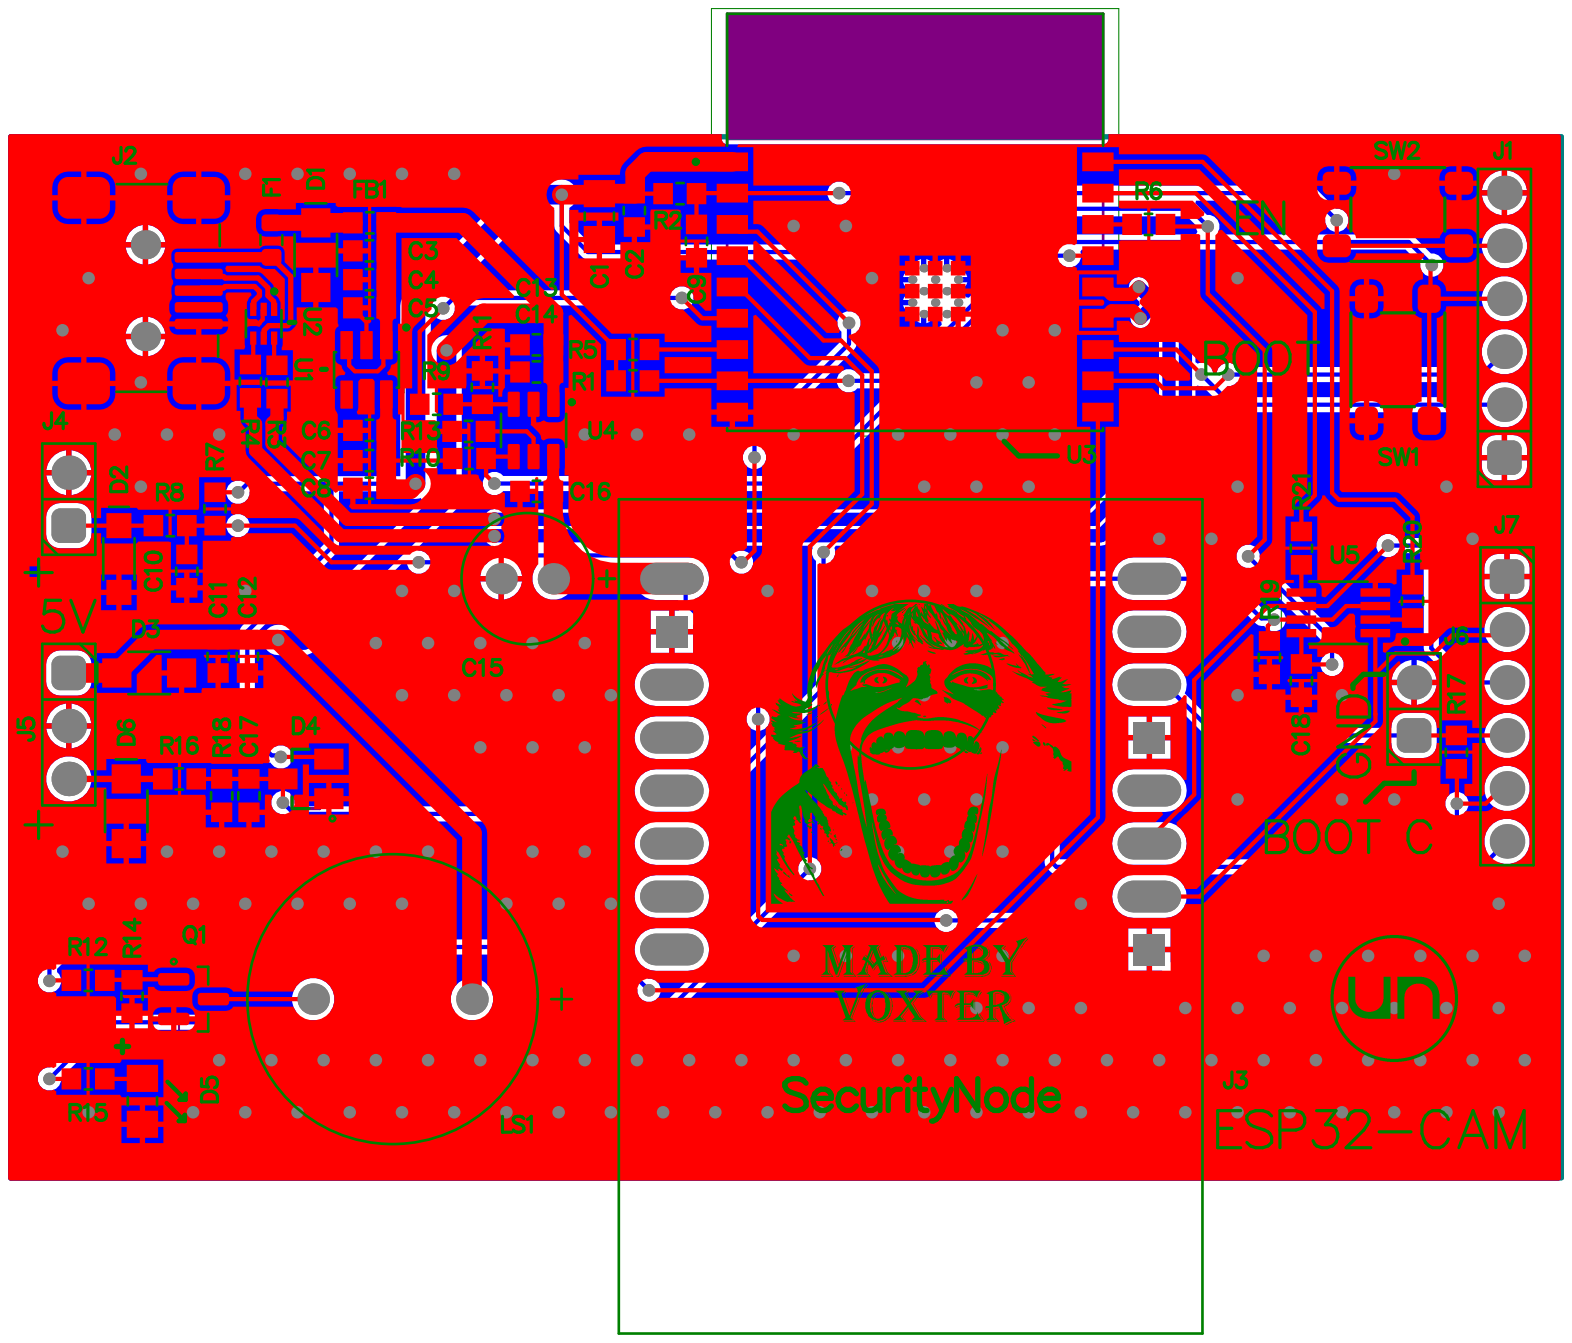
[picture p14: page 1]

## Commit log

2026-06-03 chore: initialize repository skeleton
    Add folder structure inspired by audiolab repository for the
    SecurityNode electronic design final project.
    Includes:
    - assets/ for renders and diagrams
    - docs/ for system, hardware, firmware, and software documentation
    - hardware/altium/ for PCB design files
    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
2026-06-03 docs: add hardware, firmware, and system documentation
    Add comprehensive documentation based on PCB BOM and circuit analysis:
    - docs/system/system_overview.md — project description, block diagram, requirements
    - docs/system/bringup_checklist.md — step-by-step board validation
    - docs/hardware/power_architecture.md — power tree, budget, protection
    - docs/hardware/mcu_interfaces.md — ESP32-C3 pinout, programming, expansion
    - docs/hardware/sensor_interfaces.md — door contact, PIR, auxiliary I/O
    - docs/hardware/alarm_subsystem.md — buzzer/LED driver circuits and state logic
    - docs/hardware/esp32cam_interface.md — J3 pinout, UART, power, analog switch
    - docs/firmware/firmware_archite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
2026-06-04 feat: add HTML presentation and update assets
    - Add self-contained HTML presentation in presentation/ folder
    - 11 slides for 10-min talk on SecurityNode
    - Dark professional theme, keyboard/touch navigation
    - Includes PCB renders and system diagrams
    - Copy PCB files (above.png, below.png, pcb.pdf, SecurityNode.pdf) to assets/
    - Fix Docs/.gitignore to actually ignore *.pdf and *.log files
2026-06-04 feat: update presentation per teacher guidelines
    - Restructure to 8 slides aligned with final presentation rubric:
    1. Title with institutional email
    2. Natural language description (problem, users, function, behavior)
    3. System block diagram (power, controller, sensors, actuators, vision, comms)
    4. Power tree (USB → 5V rail → two branches: TPS→CAM, LDO→3.3V)
    5. Proof of Concept: breadboard + laptop webcam + Python MediaPipe
    - Judge Method: 3 photos, majority vote, Green/Red LEDs
    6. 3D PCB renders with enclosure ideas
    7. Closing reflections (greatest difficulty: dual ESP32 power design)
    8. References template for datasheets and design guides
    - Removed schematic an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
2026-06-04 feat: presentación completa en español + PDF handout + bloques esquemático
    - Traducción completa al español de las 9 diapositivas:
    1. Título (con email institucional jevargaso@unal.edu.co)
    2. Descripción en lenguaje natural (problema, usuarios, función, comportamiento)
    3. Diagrama de bloques del sistema
    4. Árbol de potencia (USB → 5V → TPS2553→CAM / AP2112K→3.3V)
    5. Prueba de concepto: protoboard + ESP-WROOM-32 + webcam laptop
    + Python MediaPipe + Método del Jurado (3 fotos, voto mayoritario)
    6. Esquemático — bloques principales (POWER, ESP32-C3, INPUTS, OUTPUTS, ESP32-CAM+TPS2553)
    7. Render 3D de la PCB
    8. Cierre y reflexión (mayor dificultad: arqu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
2026-06-04 Restructure repo: move presentation to docs/, remove duplicate PCB_FILES/, fix ESP32-CAM wording
    - Move Docs/SecurityNode.txt -> docs/project_description.txt
    - Remove Docs/ directory (merged into docs/)
    - Move presentation/ -> docs/presentation/
    - Move Teacher Notes/ -> docs/teacher_notes/
    - Remove PCB_FILES/ (duplicates of assets/), move SecurityNode.BomDoc to assets/
    - Track assets/Schematic Blocks/ and assets/pcb.png in git
    - Fix ESP32-CAM wording: use 'switch de potencia TPS2553' instead of 'removable'
    - Update README.md repo structure
    - Regenerate PDF with corrected content
2026-06-04 Fix presentation centering and visual consistency
    - Fix text centering on all slides (title, author, email, captions)
    - Remove gradient text effect on h1 that caused alignment issues in PDF
    - Add explicit text-align: center to all heading and text elements
    - Change schematic grid from 3-col to 5-col for even 5-item layout
    - Fix left-aligned text inside centered containers (slides 5, 7, 8)
    - Add flexbox centering to .content-center for consistent alignment
    - Regenerate PDF with all fixes applied
2026-06-18 Principal altium files
    [SecurityNode.PrjPcb, SecurityNode.SchDoc]
